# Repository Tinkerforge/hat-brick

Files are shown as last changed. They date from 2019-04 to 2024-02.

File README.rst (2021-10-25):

HAT Brick
=========

This repository contains the firmware source code and the hardware design
files. The documentation generator configs can be found at
https://github.com/Tinkerforge/generators

Repository Content
------------------

software/:
 * examples/: Examples for all supported languages
 * build/: Compiled files
 * src/: Source code of firmware
 * Makefile: Makefile to build project

hardware/:
 * Contains KiCad project files and additionally schematics as PDF

datasheets/:
 * Contains datasheets for sensors and complex ICs that are used

Hardware
--------

The hardware is designed with the open source EDA Suite KiCad
(http://www.kicad.org). Before you are able to open the files,
you have to install the Tinkerforge kicad-libraries
(https://github.com/Tinkerforge/kicad-libraries). You can either clone
them directly in hardware/ or clone them in a separate folder and
symlink them into hardware/
(ln -s kicad_path/kicad-libraries project_path/hardware). After that you
can open the .pro file in hardware/ with KiCad and from there view and
modify the schematics and the PCB layout.

Software
--------

If you want to do your own Brick/Bricklet firmware development we highly
recommend that you use our build environment setup script and read the
tutorial (https://www.tinkerforge.com/en/doc/Tutorials/Tutorial_Build_Environment/Tutorial.html).

To compile the C code we recommend you to install the newest GNU Arm Embedded
Toolchain (https://launchpad.net/gcc-arm-embedded/+download).
You also need to install bricklib2 (https://github.com/Tinkerforge/bricklib2).

You can either clone it directly in software/src/ or clone it in a
separate folder and symlink it into software/src/
(ln -s bricklib_path/bricklib2 project_path/software/src/). Finally make sure to
have CMake installed (http://www.cmake.org/cmake/resources/software.html).

After that you can build the firmware by invoking make in software/.
The firmware (.zbin) can then be found in software/build/ and uploaded
with brickv (click button "Flashing" on start screen).

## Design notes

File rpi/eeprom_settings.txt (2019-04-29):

########################################################################
# EEPROM settings text file
#
# Edit this file for your particular board and run through eepmake tool,
# then use eepflash tool to write to attached HAT ID EEPROM 
#
# Tools available:
#  eepmake   Parses EEPROM text file and creates binary .eep file
#  eepdump   Dumps a binary .eep file as human readable text (for debug)
#  eepflash  Write or read .eep binary image to/from HAT EEPROM
#
########################################################################

########################################################################
# Vendor info

# 128 bit UUID. If left at zero eepmake tool will auto-generate
# RFC 4122 compliant UUID
product_uuid b7603365-412f-47ef-a4d2-e60170d12fc1

# 16 bit product id (2126)
product_id 0x084E

# 16 bit product version
product_ver 0x001

# ASCII vendor string  (max 255 characters)
vendor "Tinkerforge GmbH"

# ASCII product string (max 255 characters)
product "HAT Brick"

########################################################################
# GPIO bank settings, set to nonzero to change from the default.
# NOTE these setting can only be set per BANK, uncommenting any of
# these will force the bank to use the custom setting.

# drive strength, 0=default, 1-8=2,4,6,8,10,12,14,16mA, 9-15=reserved
gpio_drive 0

# 0=default, 1=slew rate limiting, 2=no slew limiting, 3=reserved
gpio_slew 0

# 0=default, 1=hysteresis disabled, 2=hysteresis enabled, 3=reserved
gpio_hysteresis 0

# If board back-powers Pi via 5V GPIO header pins:
# 0 = board does not back-power
# 1 = board back-powers and can supply the Pi with a minimum of 1.3A
# 2 = board back-powers and can supply the Pi with a minimum of 2A
# 3 = reserved
# If back_power=2 then USB high current mode will be automatically 
# enabled on the Pi
back_power 1

########################################################################
# GPIO pins, uncomment for GPIOs used on board
# Options for FUNCTION: INPUT, OUTPUT, ALT0-ALT5
# Options for PULL: DEFAULT, UP, DOWN, NONE
# NB GPIO0 and GPIO1 are reserved for ID EEPROM so cannot be set

#         GPIO  FUNCTION  PULL
#         ----  --------  ----
#setgpio  2     INPUT     DEFAULT
#setgpio  3     INPUT     DEFAULT
#setgpio  4     INPUT     DEFAULT
setgpio  5     OUTPUT     UP           # Chip Select
setgpio  6     OUTPUT     UP           # Chip Select
setgpio  7     OUTPUT     UP           # Chip Select
#setgpio  8     INPUT     DEFAULT
#setgpio  9     INPUT     DEFAULT
#setgpio  10    INPUT     DEFAULT
#setgpio  11    INPUT     DEFAULT
#setgpio  12    INPUT     DEFAULT
#setgpio  13    INPUT     DEFAULT
#setgpio  14    INPUT     DEFAULT
#setgpio  15    INPUT     DEFAULT
#setgpio  16    INPUT     DEFAULT
#setgpio  17    INPUT     DEFAULT
#setgpio  18    INPUT     DEFAULT
#setgpio  19    INPUT     DEFAULT
#setgpio  20    INPUT     DEFAULT
#setgpio  21    INPUT     DEFAULT
setgpio  22    OUTPUT     UP           # Chip Select
setgpio  23    OUTPUT     UP           # Chip Select
setgpio  24    OUTPUT     UP           # Chip Select
setgpio  25    OUTPUT     UP           # Chip Select
setgpio  26    OUTPUT     UP           # Chip Select
setgpio  27    OUTPUT     UP           # Chip Select

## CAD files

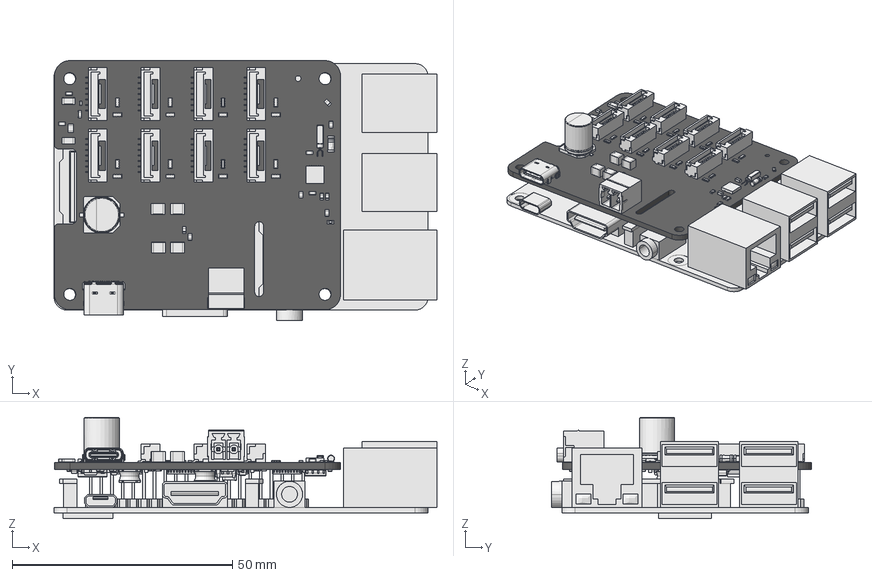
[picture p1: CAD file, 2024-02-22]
hardware/hat.FCStd
87.0 x 59.0 x 23.0 mm
Pcb_34c2
C102_C_0603_00005b3742ad
C103_C_0603_00005b3742b7
C107_C_1206_00005b3742df
C110_C_1206_00005b3742fd
C111_C_0603_00005b374307
c_el_F_D80_L100
CP301_Cut_00005b37446e
CP302_Cut_00005b37447e
CP303_Cut_00005b37448e
CP304_Cut_00005b37449e
CP305_Cut_00005b3744ae
CP306_Cut_00005b3744be
CP307_Cut_00005b3744ce
CP308_Cut_00005b3744de
L102_R_0805_00005b3745df
P201_2er_Phoenix_Buchse_Grün_00005b374602
P301_BrickletConn_7pin_180_00005b374615
P302_BrickletConn_7pin_180_00005b374628
P303_BrickletConn_7pin_180_00005b37463b
P304_BrickletConn_7pin_180_00005b37464e
P305_BrickletConn_7pin_180_00005b374661
P306_BrickletConn_7pin_180_00005b374674
P307_BrickletConn_7pin_180_00005b374687
P308_BrickletConn_7pin_180_00005b37469a
R101_R_0603_00005b3746d0
R102_R_0603_00005b3746da
RP301_Cut_00005b374814
RP302_Cut_00005b374824
RP303_Cut_00005b374834
RP304_Cut_00005b374844
RP305_Cut_00005b374854
RP306_Cut_00005b374864
RP307_Cut_00005b374874
RP308_Cut_00005b374884
R103_R_0603_00005b45ae8f
X101_AB26TRQ_00005b6d9510
C203_C_1210_00005c675905
R104_R_0603_00005c6b70e3
C114_C_0603_00005c6c6956
C116_C_0402_00005c6d4534
R105_R_0603_00005c6f29cb
U101_QFN-24_4x4mm_Pitch0.5mm_00005c6f29dc
USB4105
USB4106
C105_C_0603_00005e7b179c
C6_C_1210_f720f5794206
R2_R_0603_bf9c9aada493
R3_R_0603_2c3d8f72ff8d
C2_C_1210_26456e1a1afe
R1_R_0603_8b455849e99a
C1_C_1210_014f6602df92
C104_C_0603_00005b3742c1
C108_C_1206_00005b3742e9
C109_C_0603_00005b3742f3
C112_C_1206_00005b374311
C301_C_0603_00005b374440
C302_C_0603_00005b37444a
C303_C_0603_00005b374454
C304_C_0603_00005b37445e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

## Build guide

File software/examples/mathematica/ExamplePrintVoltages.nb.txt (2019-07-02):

Needs["NETLink`"]
LoadNETAssembly["Tinkerforge",NotebookDirectory[]<>"../../.."]

host="localhost"
port=4223
uid="XXYYZZ"(*Change XXYYZZ to the UID of your HAT Brick*)

(*Create IPConnection and device object*)
ipcon=NETNew["Tinkerforge.IPConnection"]
hat=NETNew["Tinkerforge.BrickHAT",uid,ipcon]
ipcon@Connect[host,port]

(*Get current get voltages*)
voltageUSB=0;voltageDC=0
hat@GetVoltages[voltageUSB,voltageDC]

Print["Voltage USB: "<>ToString[N[Quantity[voltageUSB,"V/1000"]]]]
Print["Voltage DC: "<>ToString[N[Quantity[voltageDC,"V/1000"]]]]

(*Clean up*)
ipcon@Disconnect[]
ReleaseNETObject[hat]
ReleaseNETObject[ipcon]

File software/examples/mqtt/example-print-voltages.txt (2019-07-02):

# Change XXYYZZ to the UID of your HAT Brick

setup:
	# Get current get voltages
	subscribe to tinkerforge/response/hat_brick/XXYYZZ/get_voltages
	publish '' to tinkerforge/request/hat_brick/XXYYZZ/get_voltages

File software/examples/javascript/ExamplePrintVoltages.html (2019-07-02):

# HAT Brick Print Voltages Example

: ,

Press "Start Example" to begin ...

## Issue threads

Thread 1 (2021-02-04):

Perform clean shutdown of Pi

bablokb, 2021-02-04:
A suggestion for the  next hardware revision: if you connect two additional pins from the mcu to the Pi you could cleanly shutdown the Pi before turning power off. The delay before going to sleep would also not be necessary anymore.

The trick is to add two overlays to `/boot/config.txt`:

    dtoverlay=gpio-shutdown,gpio_pin=x
    dtoverlay=gpio-poweroff,gpiopin=y

The first overlay will initiate shutdown, when x becomes low. When the shutdown is finished, the second overlay will pull y high and you can turn off power. Depending on the pins you choose for gpio-poweroff, you might have to implement some grace period during booting, because the pin could be high for a very short time during boot.

I checked your kicad-files and it seems that you still have two pins left.

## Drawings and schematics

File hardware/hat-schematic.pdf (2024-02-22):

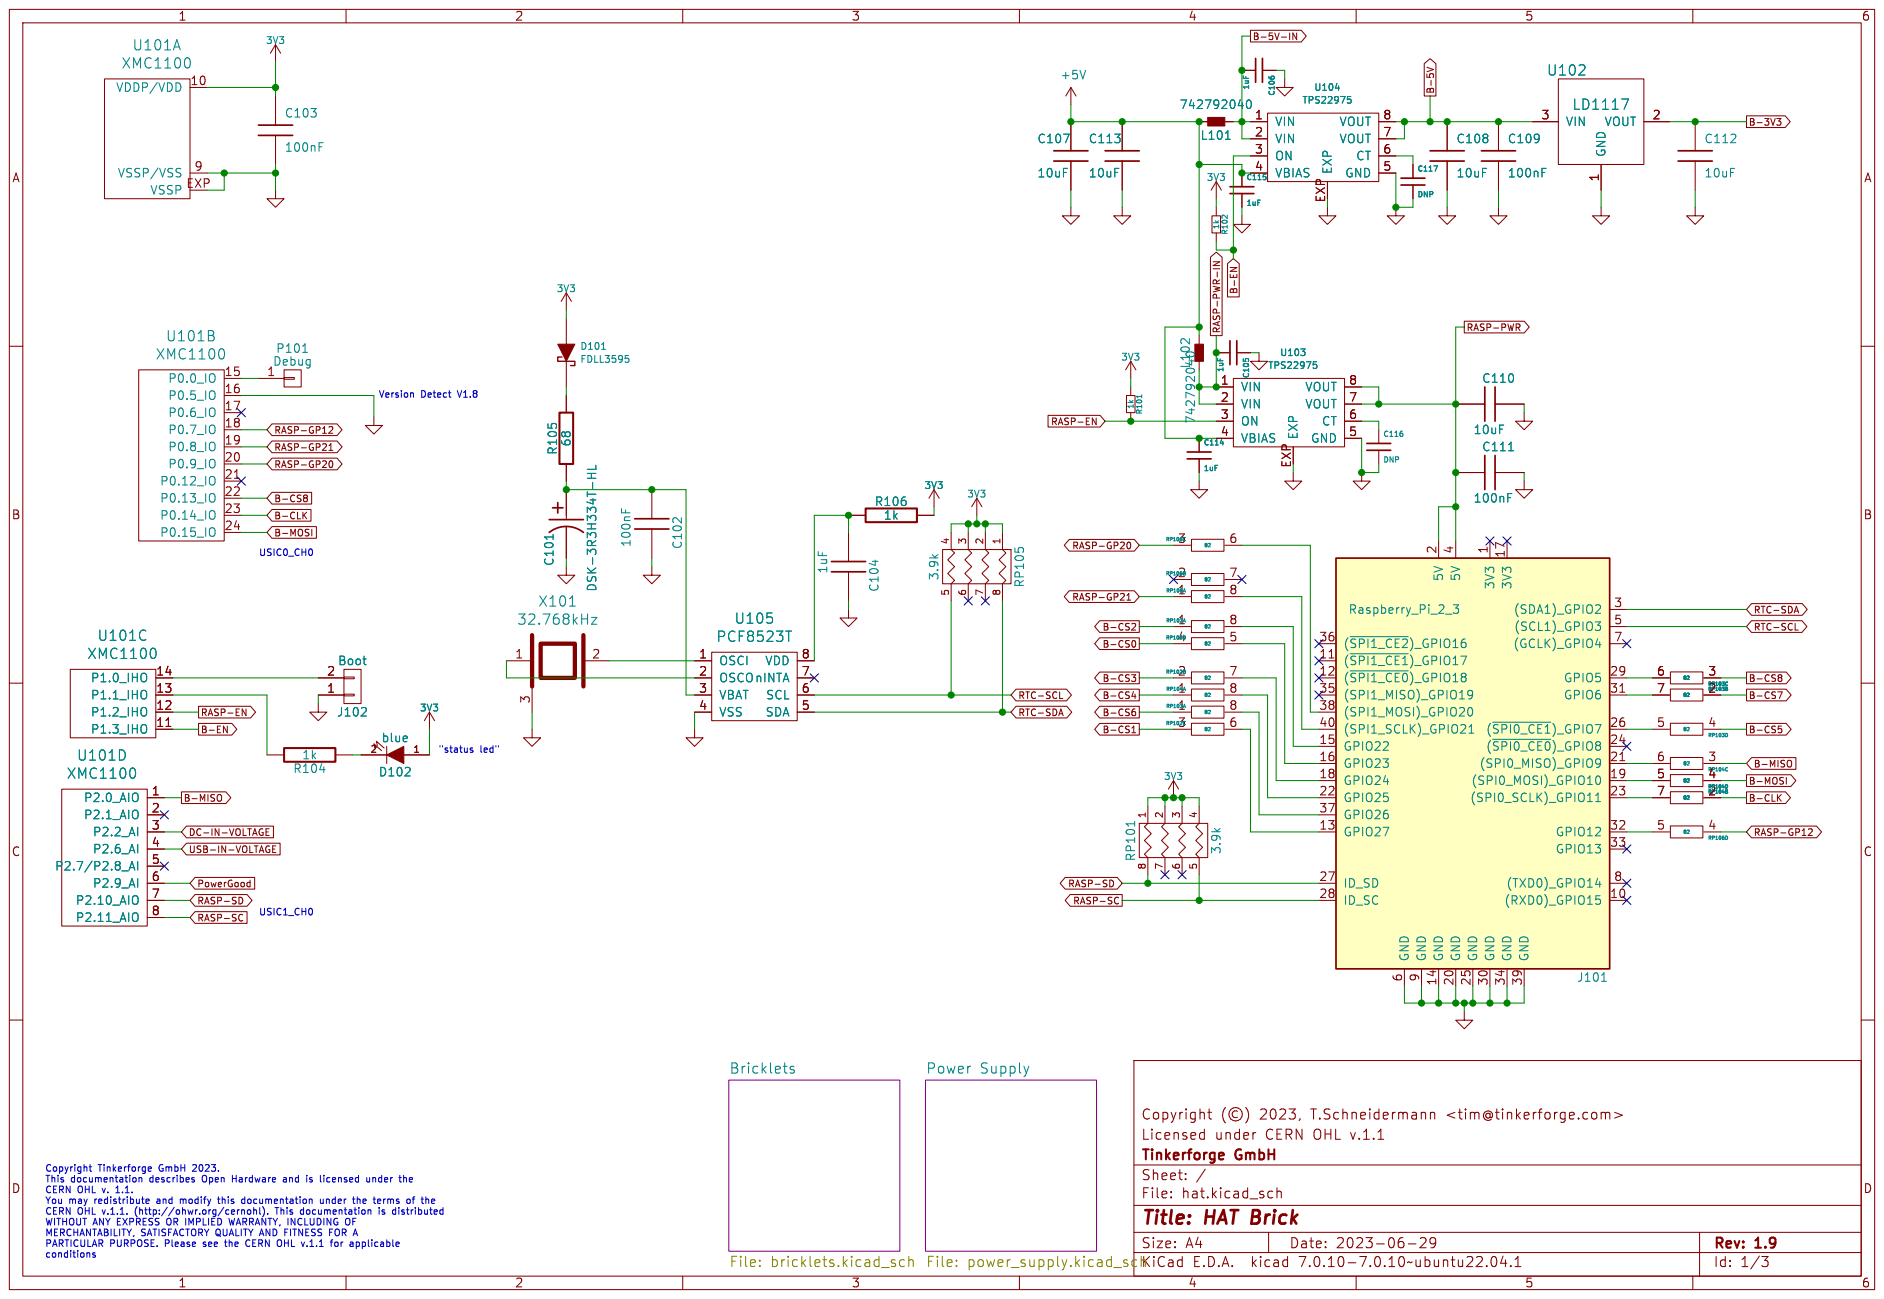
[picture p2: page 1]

PowerGood USB-IN-VOLTAGE DC-IN-VOLTAGE

File: hat.kicad_sch Sheet: / Tinkerforge GmbH

Id: 1/3 Title: HAT Brick

PARTICULAR PURPOSE. Please see the CERN OHL v.1.1 for applicable
conditions

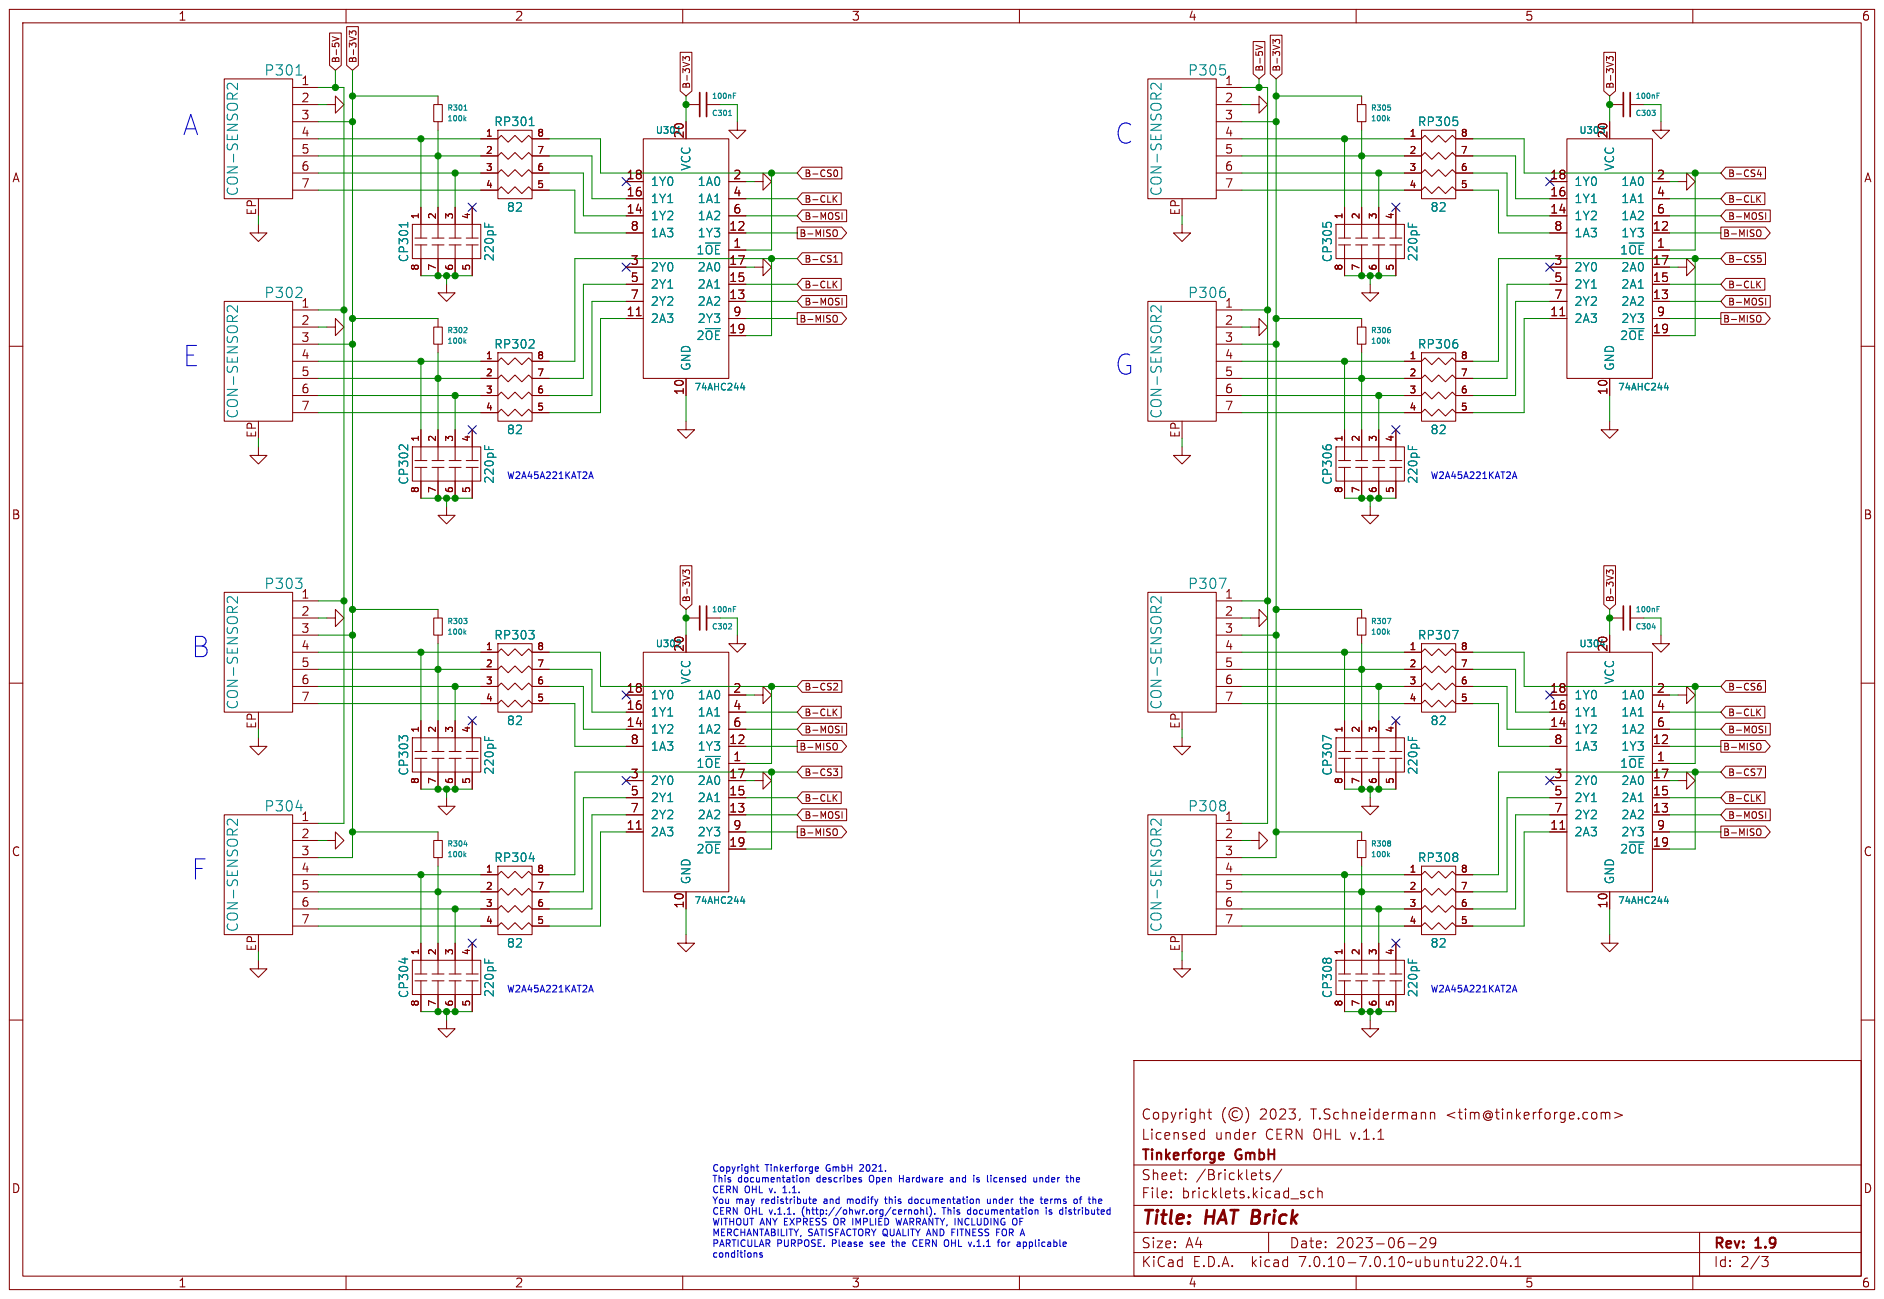
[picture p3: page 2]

File: bricklets.kicad_sch Sheet: /Bricklets/ Tinkerforge GmbH

Id: 2/3 Title: HAT Brick

PARTICULAR PURPOSE. Please see the CERN OHL v.1.1 for applicable

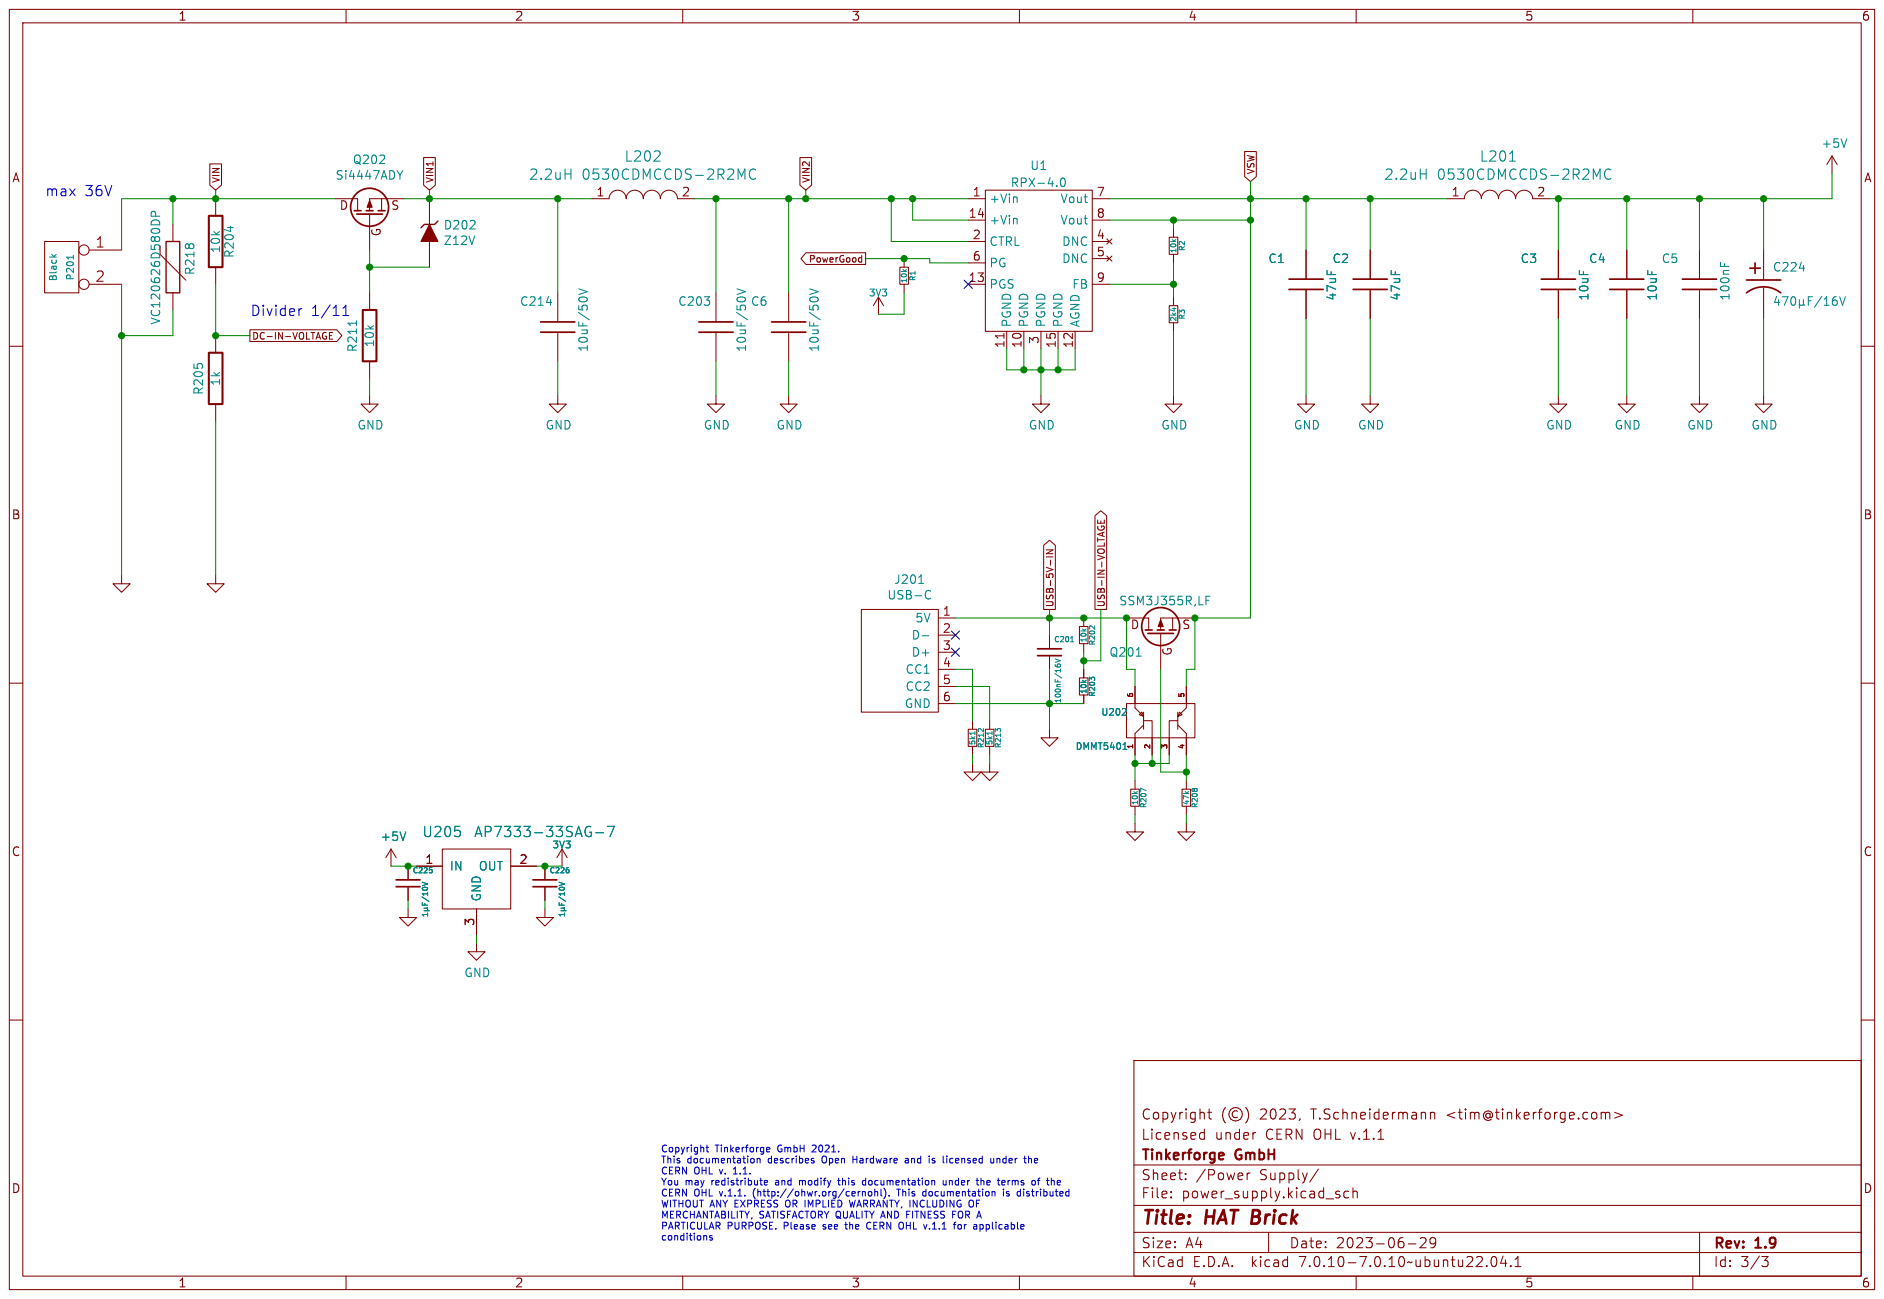
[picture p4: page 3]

3 DNC 4 DNC 5 PG 6 Vout 7 Vout 8 FB 9 U1 RPX-4.0

5 U202 DMMT5401 R203 10k +Vin 1 PGND 10 PGND 11 AGND 12 PGS 13 +Vin 14 PGND 15 CTRL 2 PGND

Tinkerforge GmbH
Id: 3/3 Title: HAT Brick

PARTICULAR PURPOSE. Please see the CERN OHL v.1.1 for applicable
conditions

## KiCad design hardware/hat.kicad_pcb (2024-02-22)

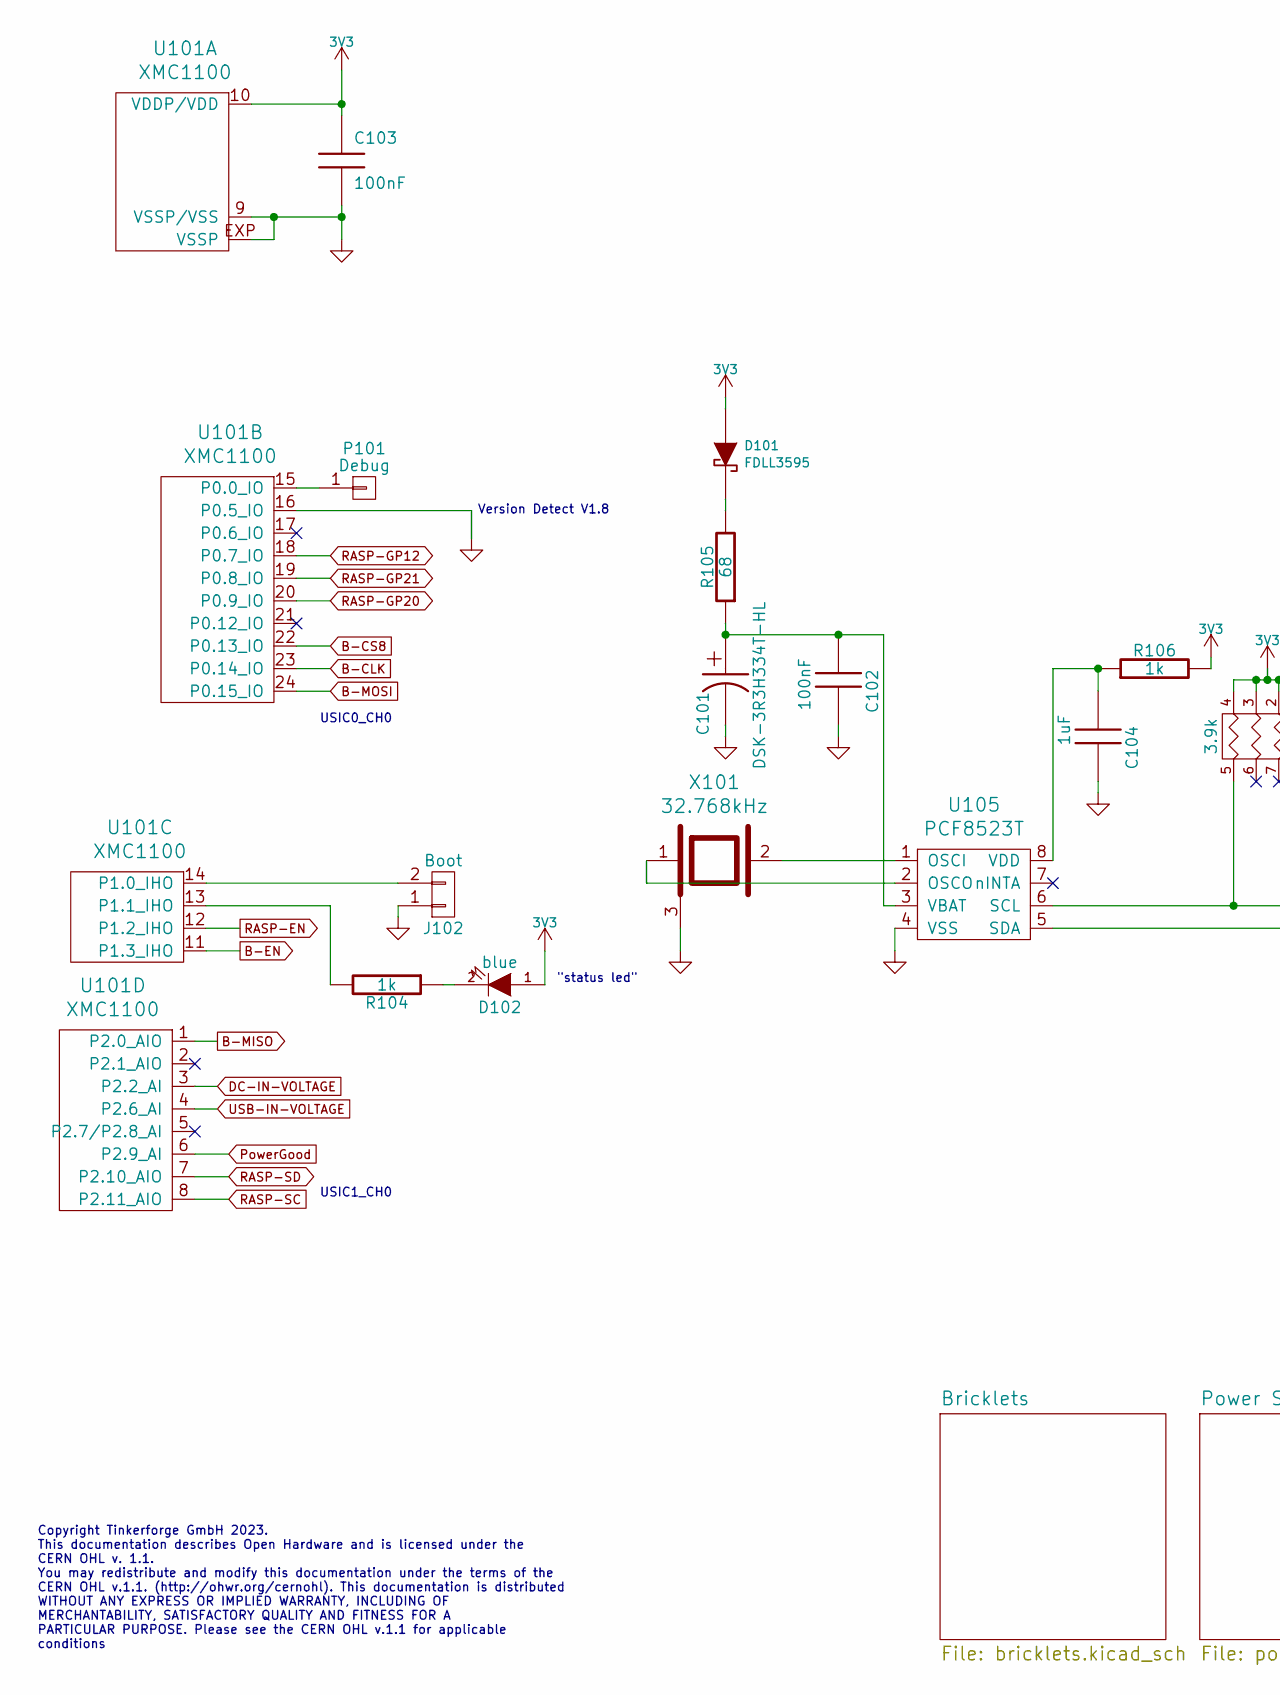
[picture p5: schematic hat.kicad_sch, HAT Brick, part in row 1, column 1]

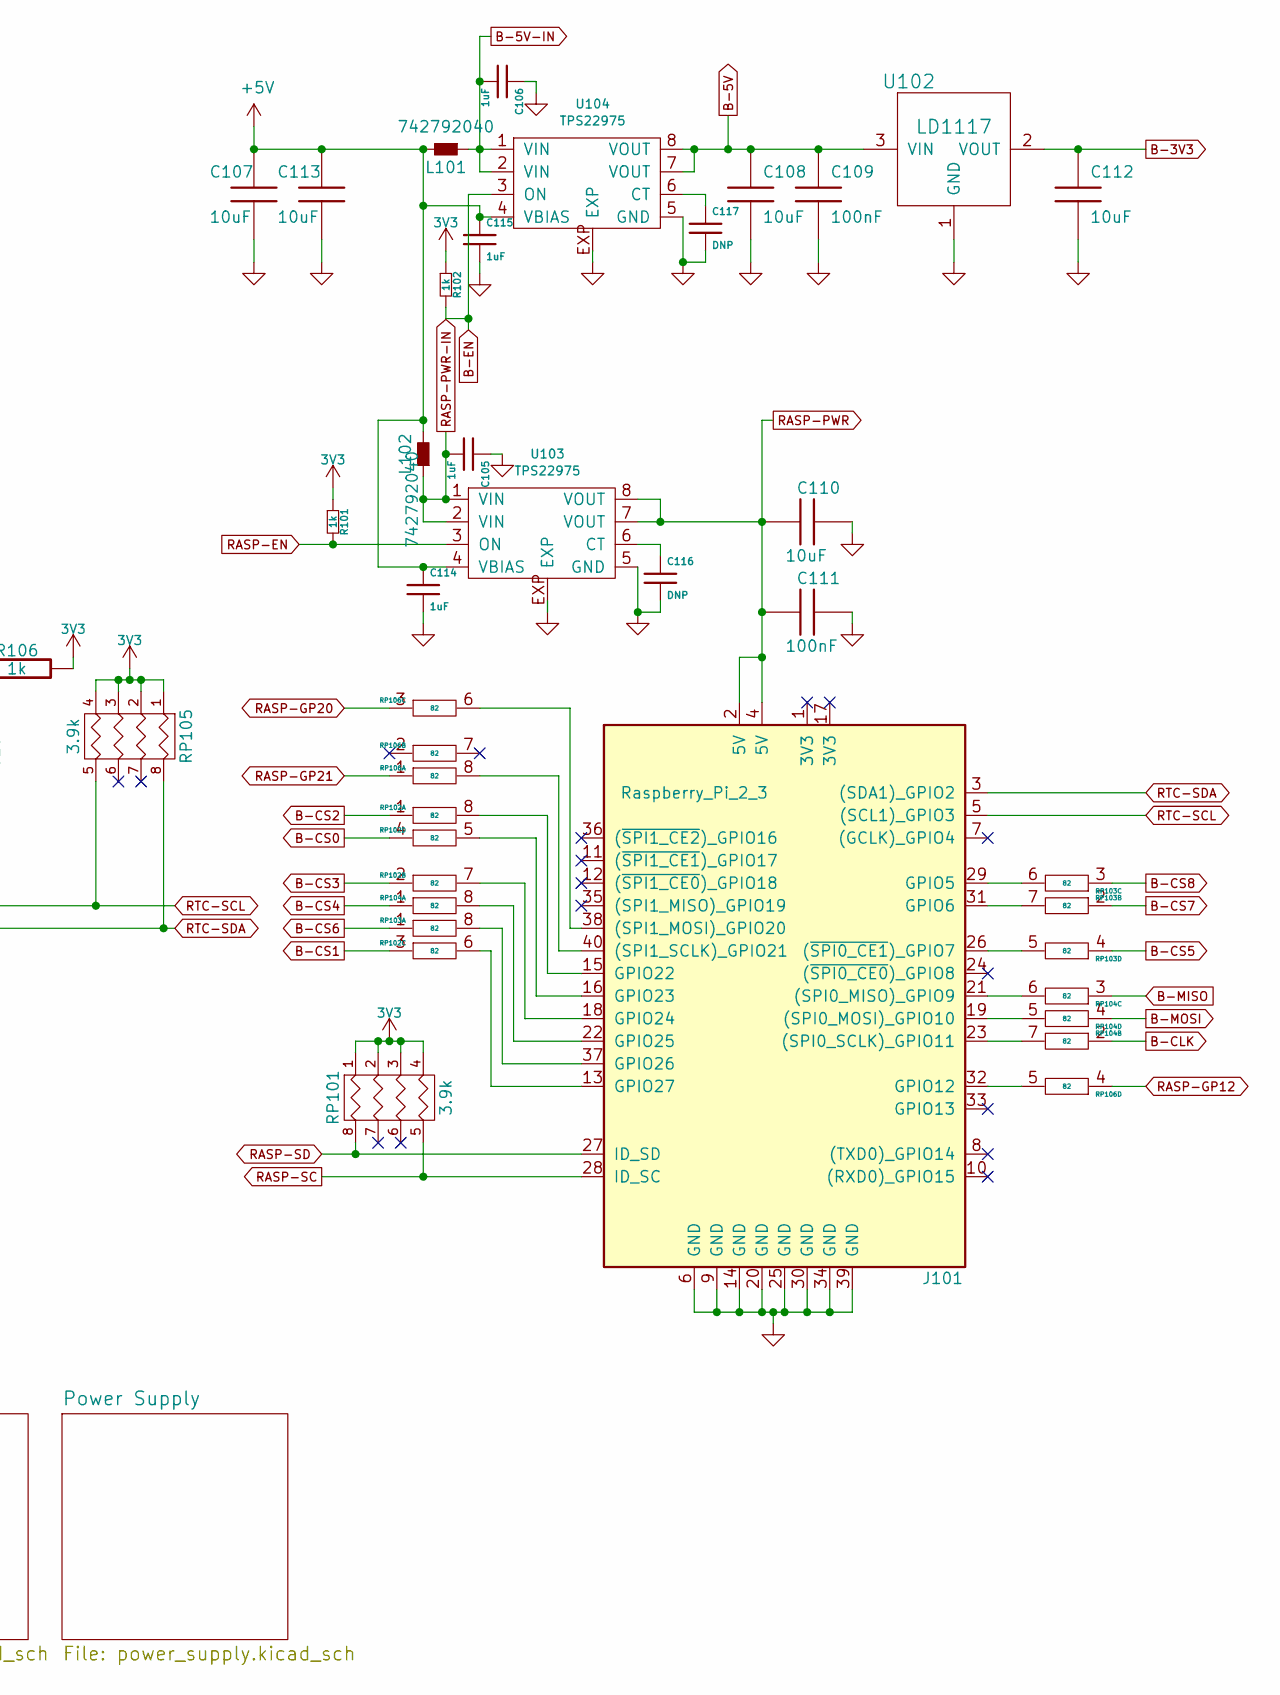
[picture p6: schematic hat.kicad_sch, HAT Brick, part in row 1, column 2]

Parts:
C101: DSK-3R3H334T-HL; DSK
C102, C103, C109, C111: 100nF; C0603F
C104, C105, C106, C114, C115: 1uF; C0603F
C107, C108, C110, C112, C113: 10uF; C1206
C116, C117: DNP; C0402F
D101: FDLL3595; MiniMelf
D102: blue; D0603F
J101: Raspberry_Pi_2_3; raspberrypi_hat2
J102: Boot; SolderJumper
L101, L102: 742792040; R0805
P101: Debug; DEBUG_PAD
R101, R102, R104, R106: 1k; R0603F
R105: 68; R0603F
RP101, RP105: 3.9k; 4X0402
RP102, RP103, RP104, RP106: 82; 4X0402
U101: XMC1100; QFN24-4x4mm-0.5mm
U102: LD1117; SOT-223
U103, U104: TPS22975; WSON8-2x2
U105: PCF8523T; SO-8
X101: 32.768kHz; AB26TRQ

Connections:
3V3: C103.1, D101.1 (A), D102.1 (A), R101.1, R102.1, R106.2, RP101.1, RP101.2, RP101.3, RP101.4, RP105.1, RP105.2, RP105.3, RP105.4, U101.10 (VDDP/VDD); also elsewhere on the board
+5V: C107.1, C113.1, C114.1, C115.1, L101.2, L102.2, U103.4 (VBIAS), U104.4 (VBIAS); also elsewhere on the board
B-3V3: C112.1, U102.2 (VOUT); also elsewhere on the board
B-5V: C108.1, C109.1, U102.3 (VIN), U104.7 (VOUT), U104.8 (VOUT); also elsewhere on the board
B-5V-IN: C106.2, L101.1, U104.1 (VIN), U104.2 (VIN)
B-CLK: RP104.2, U101.23 (P0.14_IO); also elsewhere on the board
B-CS0: RP102.4; also elsewhere on the board
B-CS1: RP102.3; also elsewhere on the board
B-CS2: RP102.1; also elsewhere on the board
B-CS3: RP102.2; also elsewhere on the board
B-CS4: RP104.1; also elsewhere on the board
B-CS5: RP103.4; also elsewhere on the board
B-CS6: RP103.1; also elsewhere on the board
B-CS7: RP103.2; also elsewhere on the board
B-CS8: RP103.3, U101.22 (P0.13_IO)
B-EN: R102.2, U101.11 (P1.3_IHO), U104.3 (ON)
B-MISO: RP104.3, U101.1 (P2.0_AIO); also elsewhere on the board
B-MOSI: RP104.4, U101.24 (P0.15_IO); also elsewhere on the board
DC-IN-VOLTAGE: U101.3 (P2.2_AI); also elsewhere on the board
GND: C101.2, C102.1, C103.2, C104.1, C105.1, C106.1, C107.2, C108.2, C109.2, C110.1, C111.1, C112.2, C113.2, C114.2, C115.2, C116.2, C117.2, J101.6 (GND), J101.9 (GND), J101.14 (GND), J101.20 (GND), J101.25 (GND), J101.30 (GND), J101.34 (GND), J101.39 (GND), J102.1, U101.9 (VSSP/VSS), U101.16 (P0.5_IO), U101.EXP (VSSP), U102.1 (GND), U103.5 (GND), U103.EXP, U104.5 (GND), U104.EXP, U105.4 (VSS), X101.3; also elsewhere on the board
unnamed: C101.1, C102.2, R105.1, U105.3 (VBAT)
unnamed: C104.2, R106.1, U105.8 (VDD)
unnamed: C116.1, U103.6 (CT)
unnamed: C117.1, U104.6 (CT)
unnamed: D101.2 (K), R105.2
unnamed: D102.2 (K), R104.1
unnamed: J101.13 (GPIO27), RP102.6
unnamed: J101.15 (GPIO22), RP102.8
unnamed: J101.16 (GPIO23), RP102.5
unnamed: J101.18 (GPIO24), RP102.7
unnamed: J101.19 ((SPI0_MOSI)_GPIO10), RP104.5
unnamed: J101.21 ((SPI0_MISO)_GPIO9), RP104.6
unnamed: J101.22 (GPIO25), RP104.8
unnamed: J101.23 ((SPI0_SCLK)_GPIO11), RP104.7
unnamed: J101.26 ((~SPI0_CE1)_GPIO7), RP103.5
unnamed: J101.29 (GPIO5), RP103.6
unnamed: J101.31 (GPIO6), RP103.7
unnamed 62: J101.32 (GPIO12), RP106.5; also elsewhere on the board
unnamed: J101.37 (GPIO26), RP103.8
unnamed: J102.2, U101.14 (P1.0_IHO)
unnamed: P101.1, U101.15 (P0.0_IO)
unnamed: R104.2, U101.13 (P1.1_IHO)
unnamed: RP106.1, U101.19 (P0.8_IO)
unnamed: RP106.3, U101.20 (P0.9_IO)
unnamed: J101.38 ((SPI1_MOSI)_GPIO20), RP106.6
unnamed: J101.40 ((SPI1_SCLK)_GPIO21), RP106.8
unnamed: U105.1 (OSCI), X101.2
unnamed: U105.2 (OSCO), X101.1
PowerGood: U101.6 (P2.9_AI); also elsewhere on the board
RASP-EN: R101.2, U101.12 (P1.2_IHO), U103.3 (ON)
RASP-GP: RP106.4, U101.18 (P0.7_IO); also elsewhere on the board
RASP-PWR: C110.2, C111.2, J101.2 (5V), J101.4 (5V), U103.7 (VOUT), U103.8 (VOUT)
RASP-PWR-IN: C105.2, L102.1, U103.1 (VIN), U103.2 (VIN)
RASP-SC: J101.28 (ID_SC), RP101.5 (R4), U101.8 (P2.11_AIO)
RASP-SD: J101.27 (ID_SD), RP101.8 (R1), U101.7 (P2.10_AIO)
RTC-SCL: J101.5 ((SCL1)_GPIO3), RP105.5 (R4), U105.6 (SCL)
RTC-SDA: J101.3 ((SDA1)_GPIO2), RP105.8 (R1), U105.5 (SDA)
USB-IN-VOLTAGE: U101.4 (P2.6_AI); also elsewhere on the board

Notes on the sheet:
"status led"
USIC1_CH0
Version Detect V1.8
Copyright Tinkerforge GmbH 2023. This documentation describes Open Hardware and is licensed under the CERN OHL v. 1.1. You may redistribute and modify this documentation under the terms of the CERN OHL v.1.1. (http://ohwr.org/cernohl). This documentation is distributed WITHOUT ANY EXPRESS OR IMPLIE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
USIC0_CH0

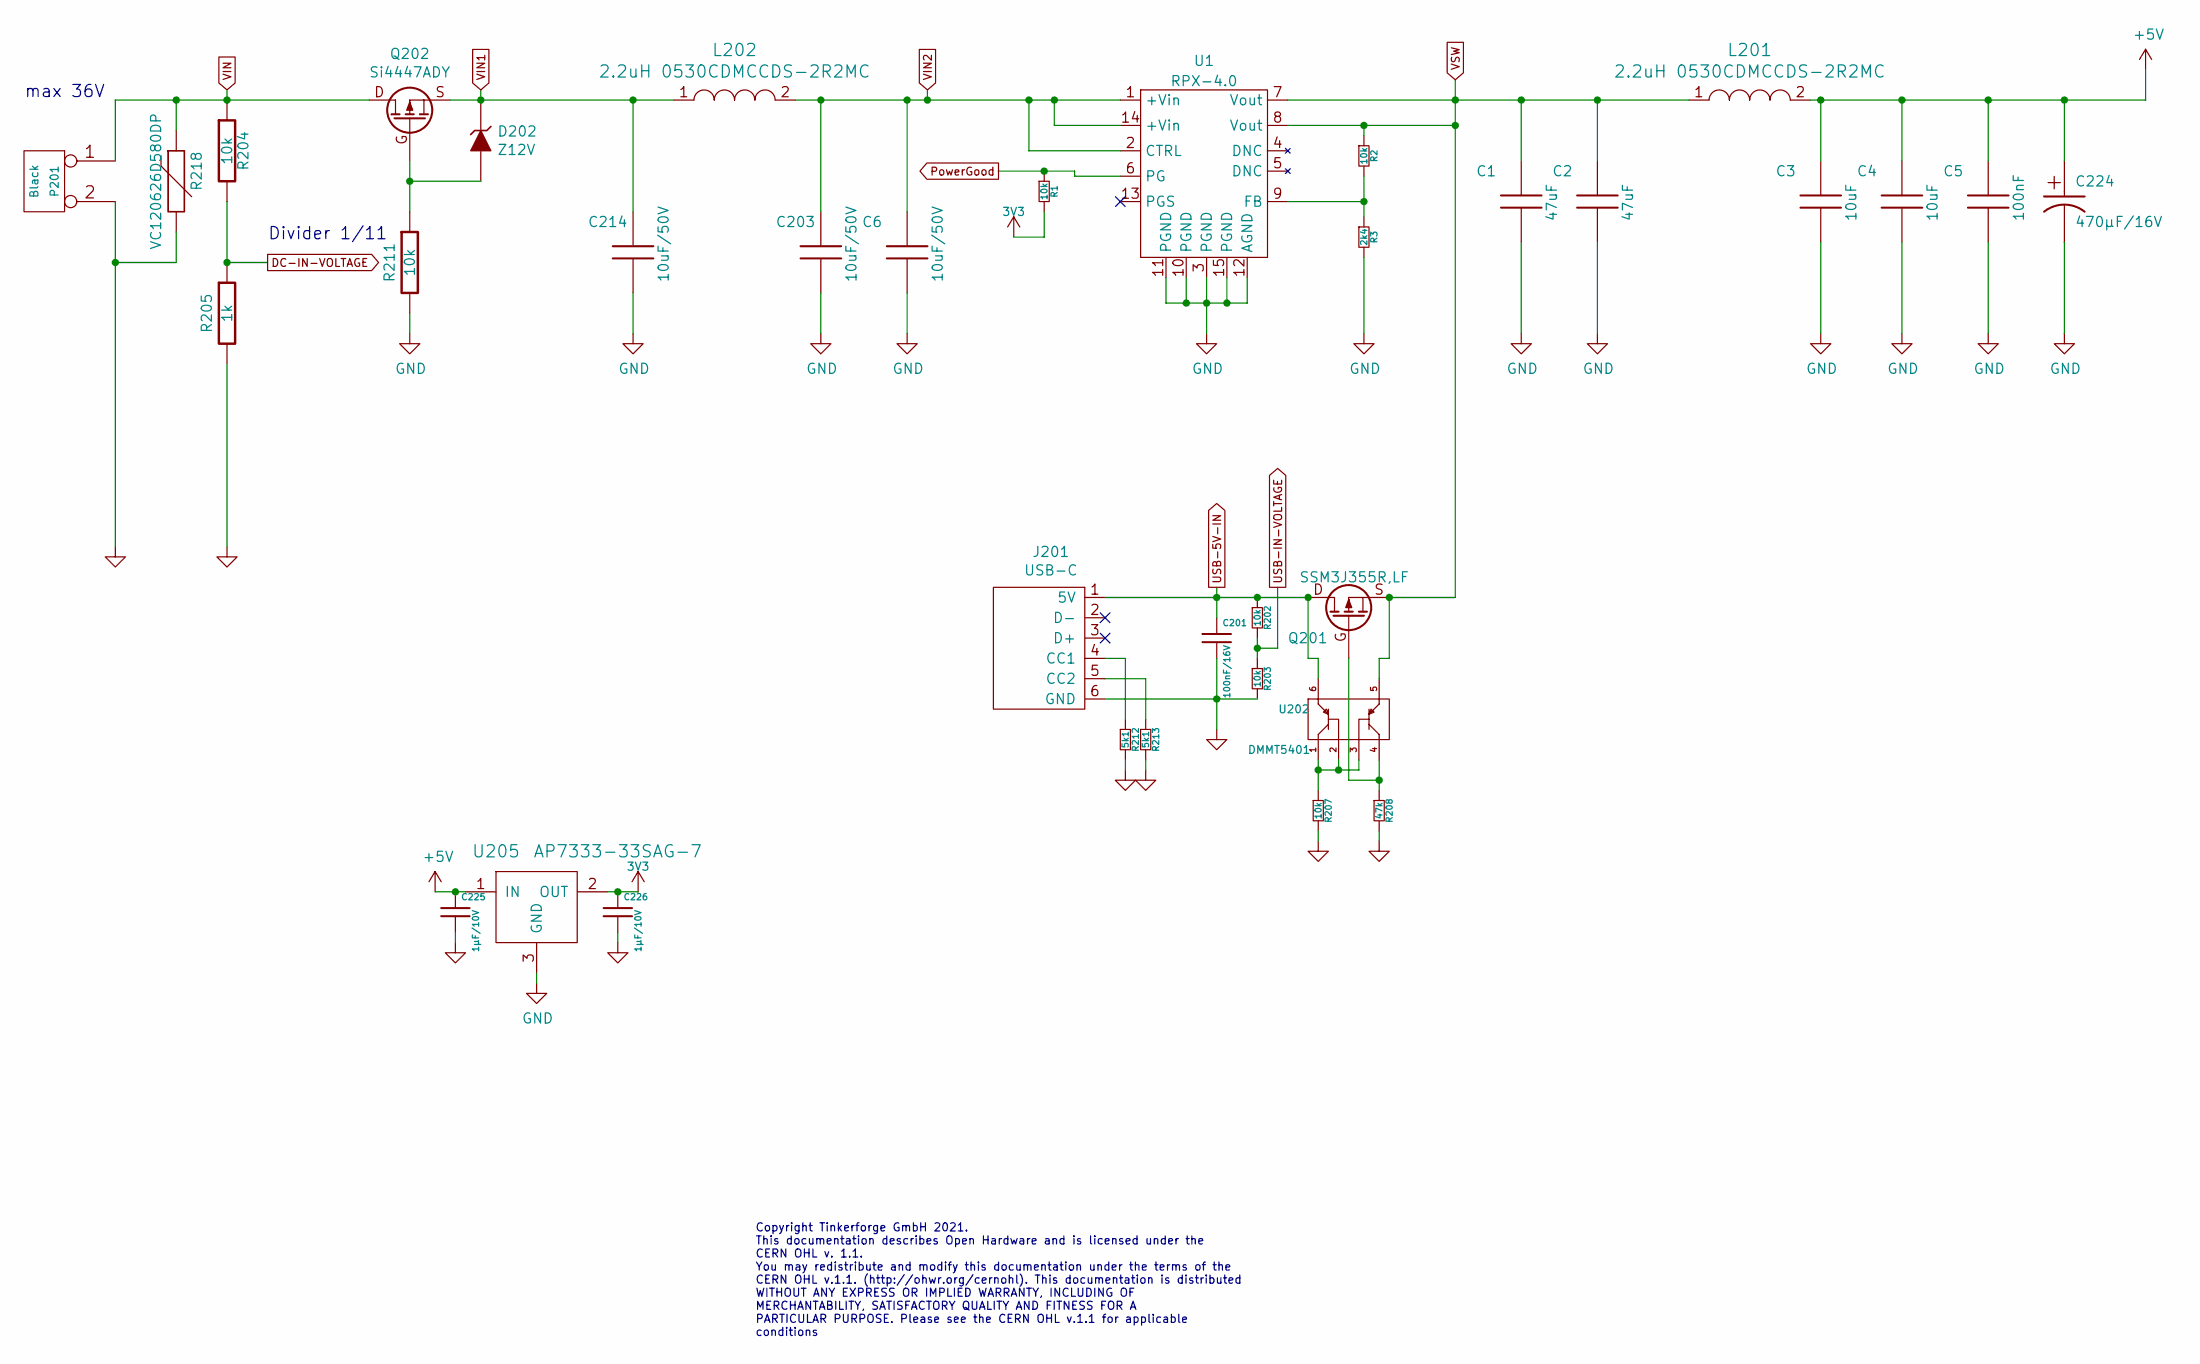
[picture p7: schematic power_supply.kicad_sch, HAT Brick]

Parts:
C1, C2: 47uF; C1210
C3, C4: 10uF; C0805E
C5: 100nF; C0603F
C6, C203, C214: 10uF/50V; C1210
C201: 100nF/16V; C0603F
C224: 470µF/16V; ELKO_83
C225, C226: 1µF/10V; C0603F
D202: Z12V; SOD-123
J201: USB-C
L201, L202: 2.2uH 0530CDMCCDS-2R2MC; NRS5030
P201: Black; OQ_2P
Q201: SSM3J355R,LF; SOT23GDS
Q202: Si4447ADY; SOIC-8-MOSFET
R1, R2, R202, R203, R204, R207, R211: 10k; R0603F
R3: 2k4; R0603F
R205: 1k; R0603F
R208: 47k; R0603F
R212, R213: 5k1; R0603F
R218: VC120626D580DP; R1206
U1: RPX-4.0
U202: DMMT5401; SOT26
U205: AP7333-33SAG-7; SOT23-3

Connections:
3V3: C226.1, R1.2, U205.2 (OUT); also elsewhere on the board
+5V: C3.1, C4.1, C5.1, C224.1, C225.1, L201.2, U205.1 (IN); also elsewhere on the board
DC-IN-VOLTAGE: R204.2, R205.1; also elsewhere on the board
GND: C1.2, C2.2, C3.2, C4.2, C5.2, C6.2, C201.2, C203.2, C214.2, C224.2, C225.2, C226.2, J201.6 (GND), P201.2 (PM), R3.2, R203.2, R205.2, R207.2, R208.2, R211.2, R212.2, R213.2, R218.2, U1.3 (PGND), U1.10 (PGND), U1.11 (PGND), U1.12 (AGND), U1.15 (PGND), U205.3 (GND); also elsewhere on the board
unnamed: D202.1 (A), Q202.G, R211.1
unnamed: J201.4 (CC1), R212.1
unnamed: J201.5 (CC2), R213.1
unnamed: Q201.G, R208.1, U202.4
unnamed: R2.2, R3.1, U1.9 (FB)
unnamed: R207.1, U202.1, U202.2, U202.3
PowerGood: R1.1, U1.6 (PG); also elsewhere on the board
USB-5V-IN: C201.1, J201.1 (5V), Q201.D, R202.1, U202.6
USB-IN-VOLTAGE: R202.2, R203.1; also elsewhere on the board
VIN: P201.1, Q202.D, R204.1, R218.1
VIN1: C214.1, D202.2 (K), L202.1, Q202.S
VIN2: C6.1, C203.1, L202.2, U1.1 (+Vin), U1.2 (CTRL), U1.14 (+Vin)
VSW: C1.1, C2.1, L201.1, Q201.S, R2.1, U1.7 (Vout), U1.8 (Vout), U202.5

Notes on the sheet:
Divider 1/11
Copyright Tinkerforge GmbH 2021. This documentation describes Open Hardware and is licensed under the CERN OHL v. 1.1. You may redistribute and modify this documentation under the terms of the CERN OHL v.1.1. (http://ohwr.org/cernohl). This documentation is distributed WITHOUT ANY EXPRESS OR IMPLIE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
max 36V

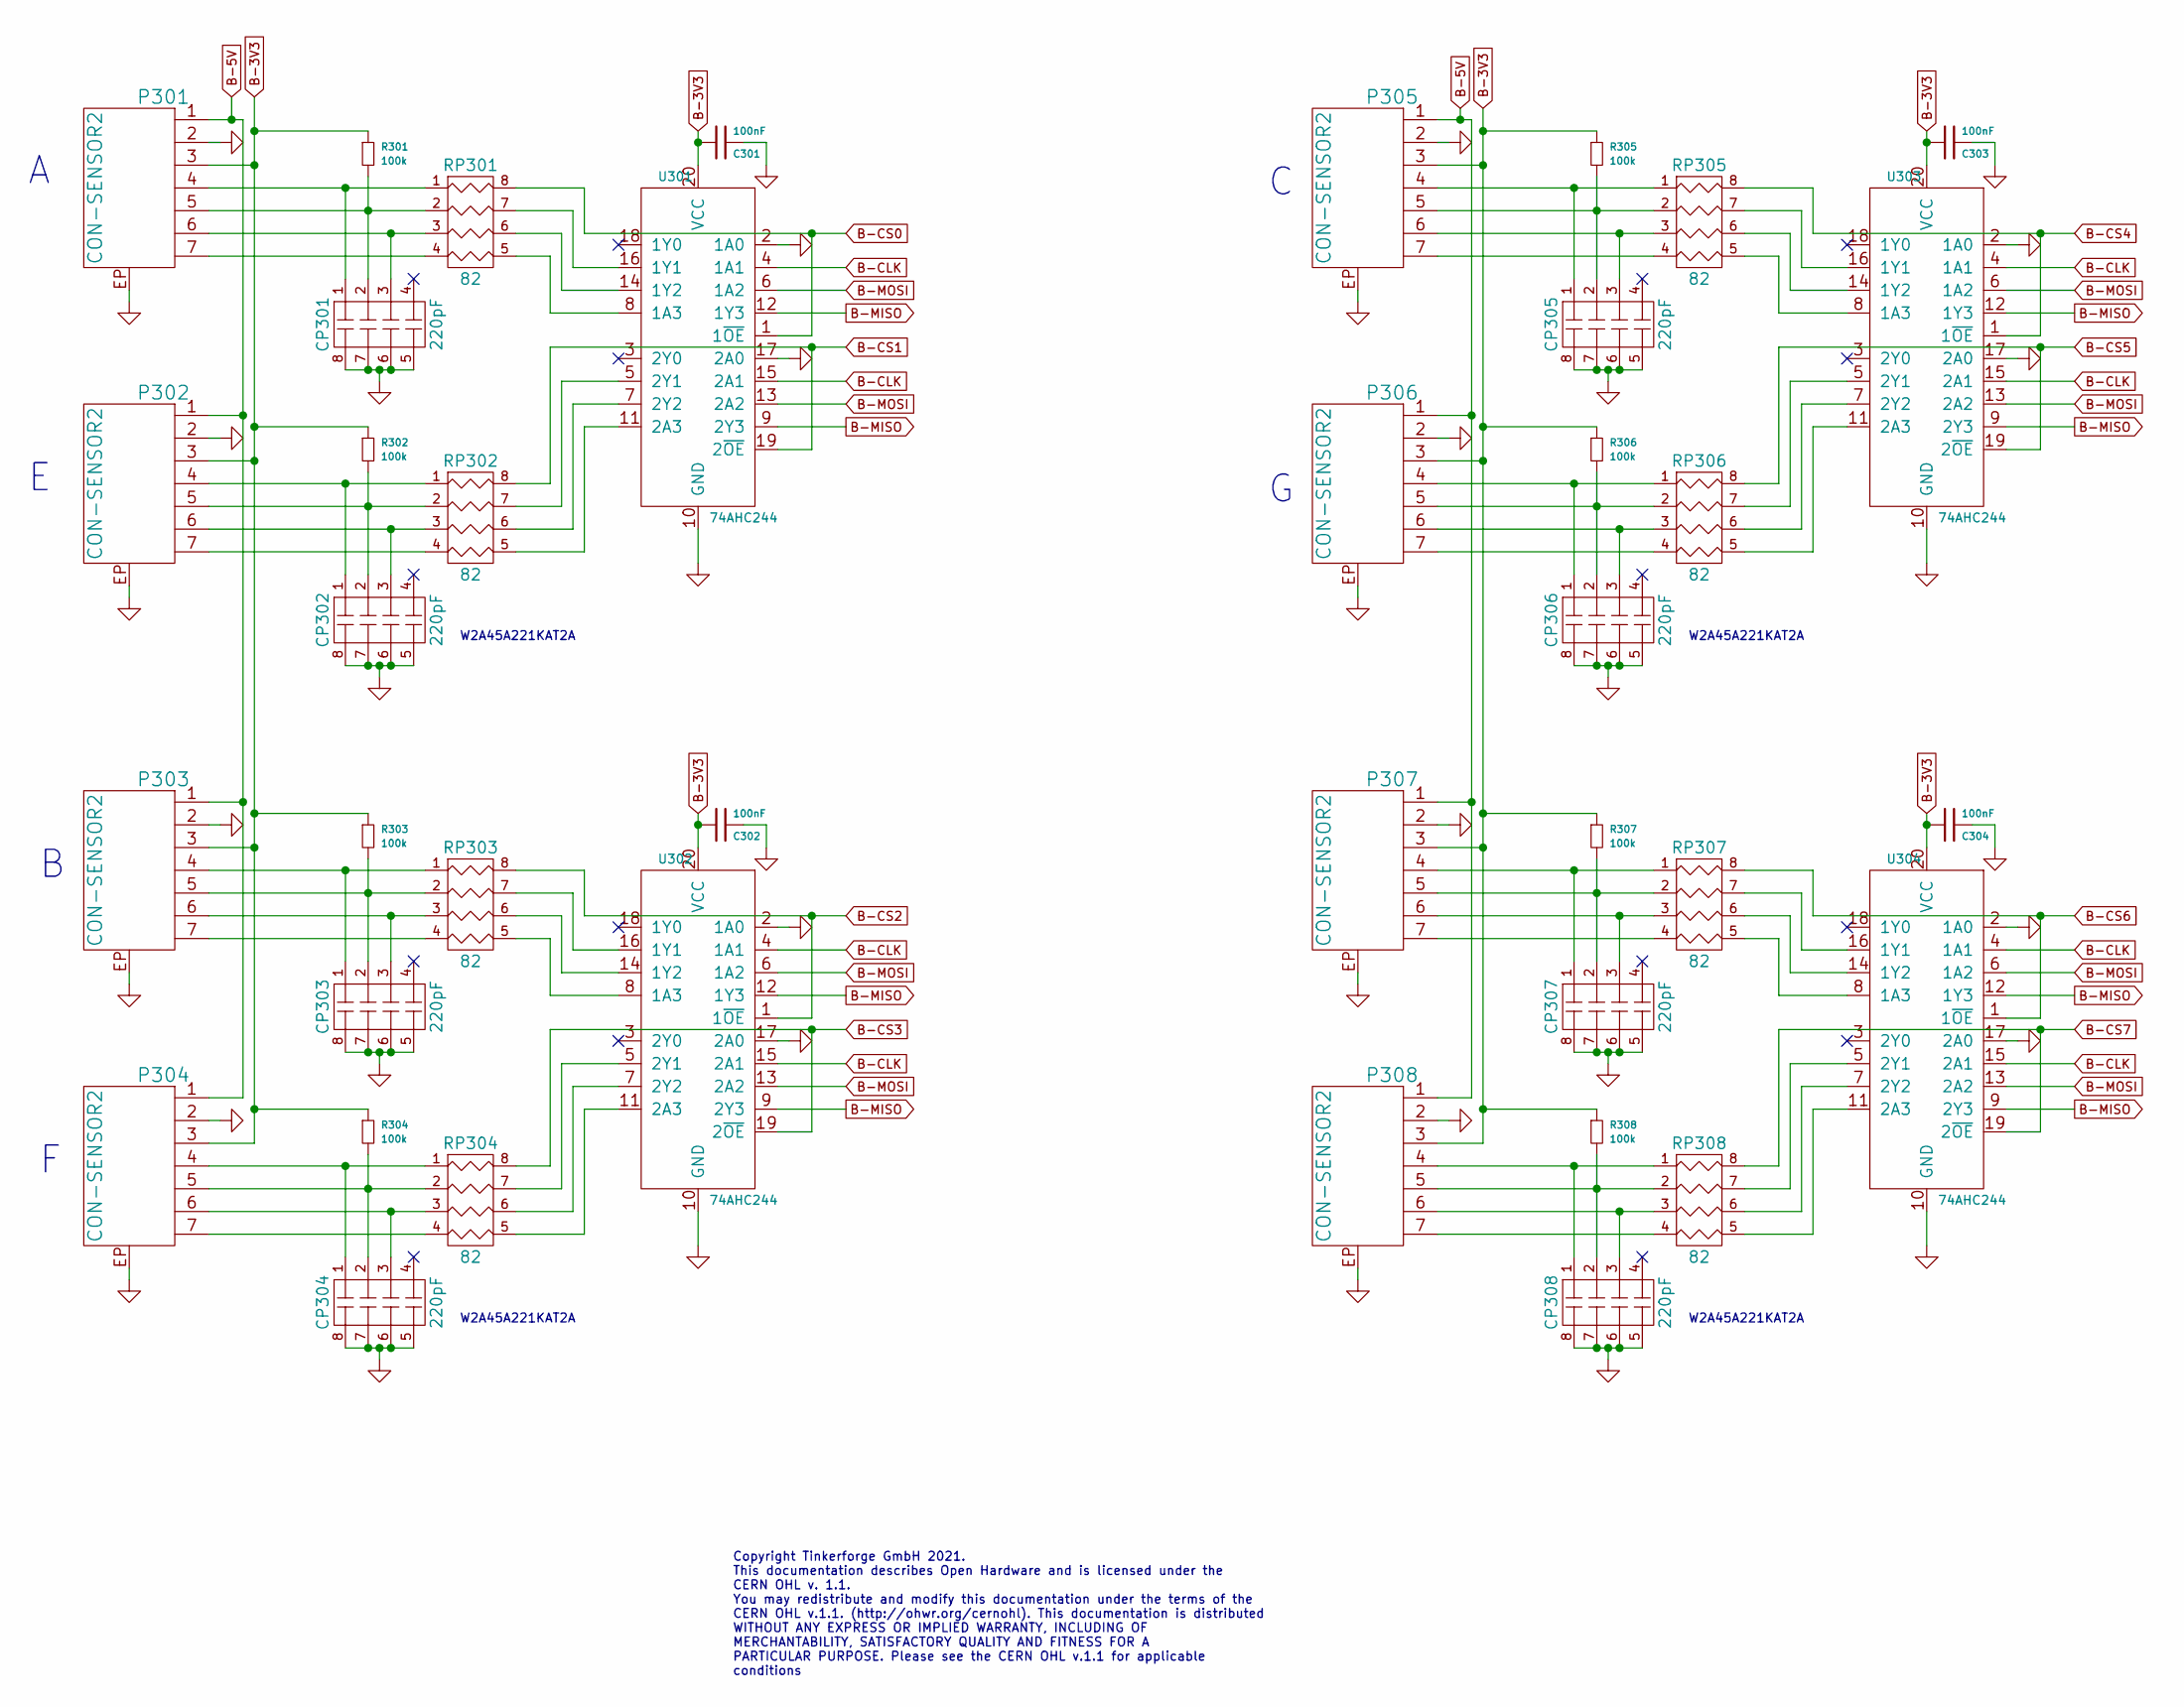
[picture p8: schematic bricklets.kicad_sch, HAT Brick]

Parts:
C301, C302, C303, C304: 100nF; C0603F
CP301, CP302, CP303, CP304, CP305, CP306, CP307, CP308: 220pF; 4X0402
P301, P302, P303, P304, P305, P306, P307, P308: CON-SENSOR2; CON-SENSOR2_180
R301, R302, R303, R304, R305, R306, R307, R308: 100k; R0402F
RP301, RP302, RP303, RP304, RP305, RP306, RP307, RP308: 82; 4X0402
U301, U302, U303, U304: 74AHC244; TSSOP20

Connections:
B-3V3: C301.2, C302.2, C303.2, C304.2, P301.3, P302.3, P303.3, P304.3, P305.3, P306.3, P307.3, P308.3, R301.1, R302.1, R303.1, R304.1, R305.1, R306.1, R307.1, R308.1, U301.20 (VCC), U302.20 (VCC), U303.20 (VCC), U304.20 (VCC); also elsewhere on the board
B-5V: P301.1, P302.1, P303.1, P304.1, P305.1, P306.1, P307.1, P308.1; also elsewhere on the board
B-CLK: U301.4 (1A1), U301.15 (2A1), U302.4 (1A1), U302.15 (2A1), U303.4 (1A1), U303.15 (2A1), U304.4 (1A1), U304.15 (2A1); also elsewhere on the board
B-CS0: RP301.8 (R1), U301.1 (1~OE); also elsewhere on the board
B-CS1: RP302.8 (R1), U301.19 (2~OE); also elsewhere on the board
B-CS2: RP303.8 (R1), U302.1 (1~OE); also elsewhere on the board
B-CS3: RP304.8 (R1), U302.19 (2~OE); also elsewhere on the board
B-CS4: RP305.8 (R1), U303.1 (1~OE); also elsewhere on the board
B-CS5: RP306.8 (R1), U303.19 (2~OE); also elsewhere on the board
B-CS6: RP307.8 (R1), U304.1 (1~OE); also elsewhere on the board
B-CS7: RP308.8 (R1), U304.19 (2~OE); also elsewhere on the board
B-MISO: U301.9 (2Y3), U301.12 (1Y3), U302.9 (2Y3), U302.12 (1Y3), U303.9 (2Y3), U303.12 (1Y3), U304.9 (2Y3), U304.12 (1Y3); also elsewhere on the board
B-MOSI: U301.6 (1A2), U301.13 (2A2), U302.6 (1A2), U302.13 (2A2), U303.6 (1A2), U303.13 (2A2), U304.6 (1A2), U304.13 (2A2); also elsewhere on the board
GND: C301.1, C302.1, C303.1, C304.1, CP301.5 (R4), CP301.6 (R3), CP301.7 (R2), CP301.8 (R1), CP302.5 (R4), CP302.6 (R3), CP302.7 (R2), CP302.8 (R1), CP303.5 (R4), CP303.6 (R3), CP303.7 (R2), CP303.8 (R1), CP304.5 (R4), CP304.6 (R3), CP304.7 (R2), CP304.8 (R1), CP305.5 (R4), CP305.6 (R3), CP305.7 (R2), CP305.8 (R1), CP306.5 (R4), CP306.6 (R3), CP306.7 (R2), CP306.8 (R1), CP307.5 (R4), CP307.6 (R3), CP307.7 (R2), CP307.8 (R1), CP308.5 (R4), CP308.6 (R3), CP308.7 (R2), CP308.8 (R1), P301.2, P301.EP, P302.2, P302.EP, P303.2, P303.EP, P304.2, P304.EP, P305.2, P305.EP, P306.2, P306.EP, P307.2, P307.EP, P308.2, P308.EP, U301.2 (1A0), U301.10 (GND), U301.17 (2A0), U302.2 (1A0), U302.10 (GND), U302.17 (2A0), U303.2 (1A0), U303.10 (GND), U303.17 (2A0), U304.2 (1A0), U304.10 (GND), U304.17 (2A0); also elsewhere on the board
unnamed: CP301.1, P301.4, RP301.1
unnamed: CP301.2, P301.5, R301.2, RP301.2
unnamed: CP301.3, P301.6, RP301.3
unnamed: CP302.1, P302.4, RP302.1
unnamed: CP302.2, P302.5, R302.2, RP302.2
unnamed: CP302.3, P302.6, RP302.3
unnamed: CP303.1, P303.4, RP303.1
unnamed: CP303.2, P303.5, R303.2, RP303.2
unnamed: CP303.3, P303.6, RP303.3
unnamed: CP304.1, P304.4, RP304.1
unnamed: CP304.2, P304.5, R304.2, RP304.2
unnamed: CP304.3, P304.6, RP304.3
unnamed: CP305.1, P305.4, RP305.1
unnamed: CP305.2, P305.5, R305.2, RP305.2
unnamed: CP305.3, P305.6, RP305.3
unnamed: CP306.1, P306.4, RP306.1
unnamed: CP306.2, P306.5, R306.2, RP306.2
unnamed: CP306.3, P306.6, RP306.3
unnamed: CP307.1, P307.4, RP307.1
unnamed: CP307.2, P307.5, R307.2, RP307.2
unnamed: CP307.3, P307.6, RP307.3
unnamed: CP308.1, P308.4, RP308.1
unnamed: CP308.2, P308.5, R308.2, RP308.2
unnamed: CP308.3, P308.6, RP308.3
unnamed: P301.7, RP301.4
unnamed: P302.7, RP302.4
unnamed: P303.7, RP303.4
unnamed: P304.7, RP304.4
unnamed: P305.7, RP305.4
unnamed: P306.7, RP306.4
unnamed: P307.7, RP307.4
unnamed: P308.7, RP308.4
unnamed: RP301.5 (R4), U301.8 (1A3)
unnamed: RP301.6 (R3), U301.14 (1Y2)
unnamed: RP301.7 (R2), U301.16 (1Y1)
unnamed: RP302.5 (R4), U301.11 (2A3)
unnamed: RP302.6 (R3), U301.7 (2Y2)
unnamed: RP302.7 (R2), U301.5 (2Y1)
unnamed: RP303.5 (R4), U302.8 (1A3)
unnamed: RP303.6 (R3), U302.14 (1Y2)
unnamed: RP303.7 (R2), U302.16 (1Y1)
unnamed: RP304.5 (R4), U302.11 (2A3)
unnamed: RP304.6 (R3), U302.7 (2Y2)
unnamed: RP304.7 (R2), U302.5 (2Y1)
unnamed: RP305.5 (R4), U303.8 (1A3)
unnamed: RP305.6 (R3), U303.14 (1Y2)
unnamed: RP305.7 (R2), U303.16 (1Y1)
unnamed: RP306.5 (R4), U303.11 (2A3)
unnamed: RP306.6 (R3), U303.7 (2Y2)
unnamed: RP306.7 (R2), U303.5 (2Y1)
unnamed: RP307.5 (R4), U304.8 (1A3)
unnamed: RP307.6 (R3), U304.14 (1Y2)
unnamed: RP307.7 (R2), U304.16 (1Y1)
unnamed: RP308.5 (R4), U304.11 (2A3)
unnamed: RP308.6 (R3), U304.7 (2Y2)
unnamed: RP308.7 (R2), U304.5 (2Y1)

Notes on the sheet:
W2A45A221KAT2A
Copyright Tinkerforge GmbH 2021. This documentation describes Open Hardware and is licensed under the CERN OHL v. 1.1. You may redistribute and modify this documentation under the terms of the CERN OHL v.1.1. (http://ohwr.org/cernohl). This documentation is distributed WITHOUT ANY EXPRESS OR IMPLIE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

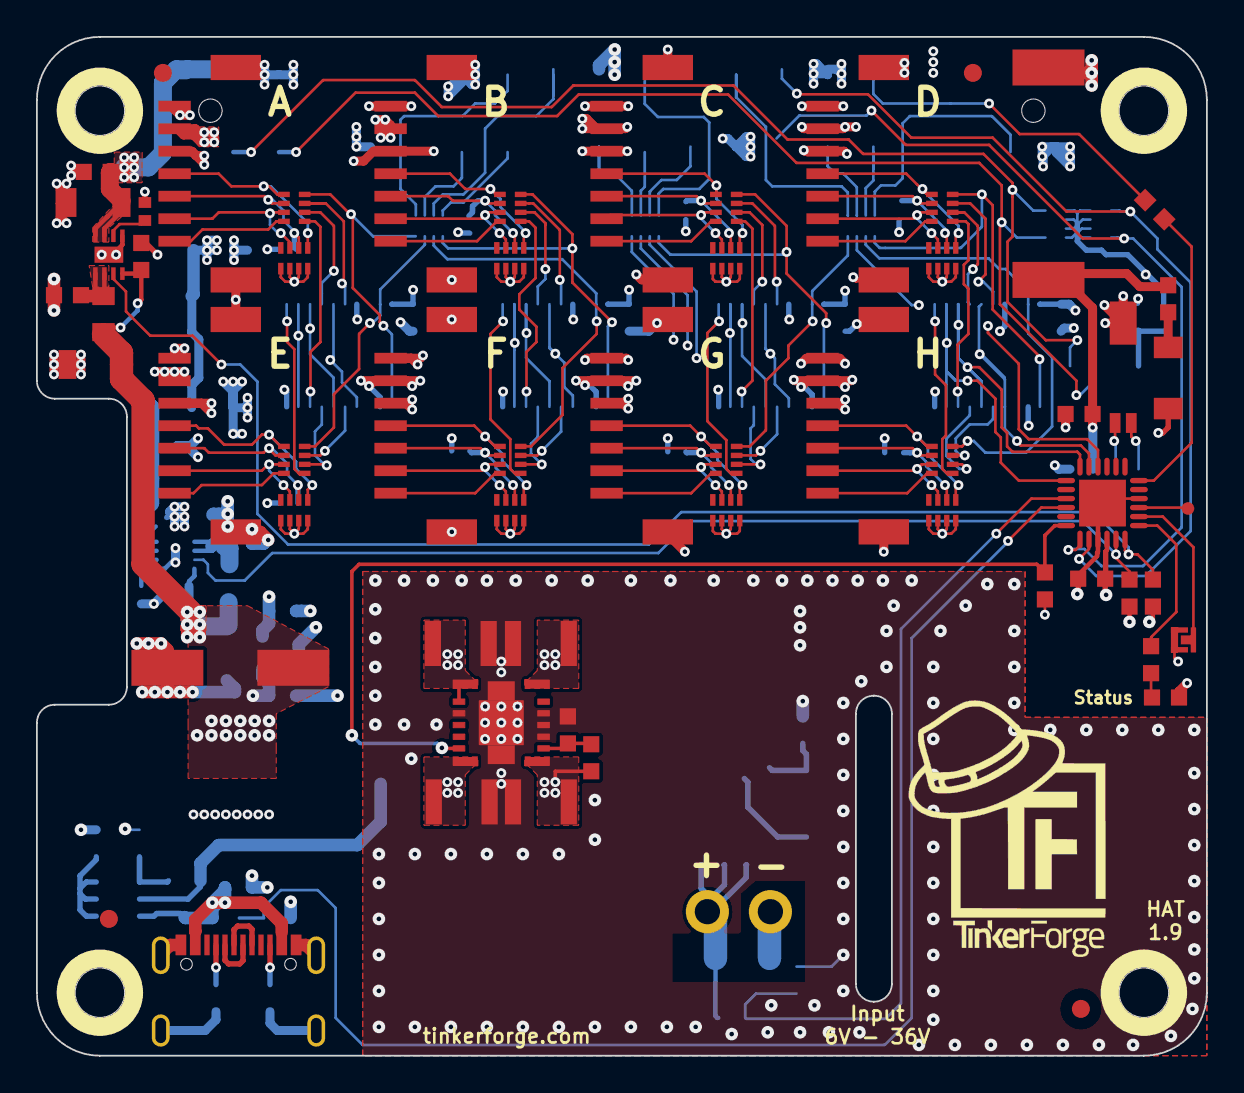
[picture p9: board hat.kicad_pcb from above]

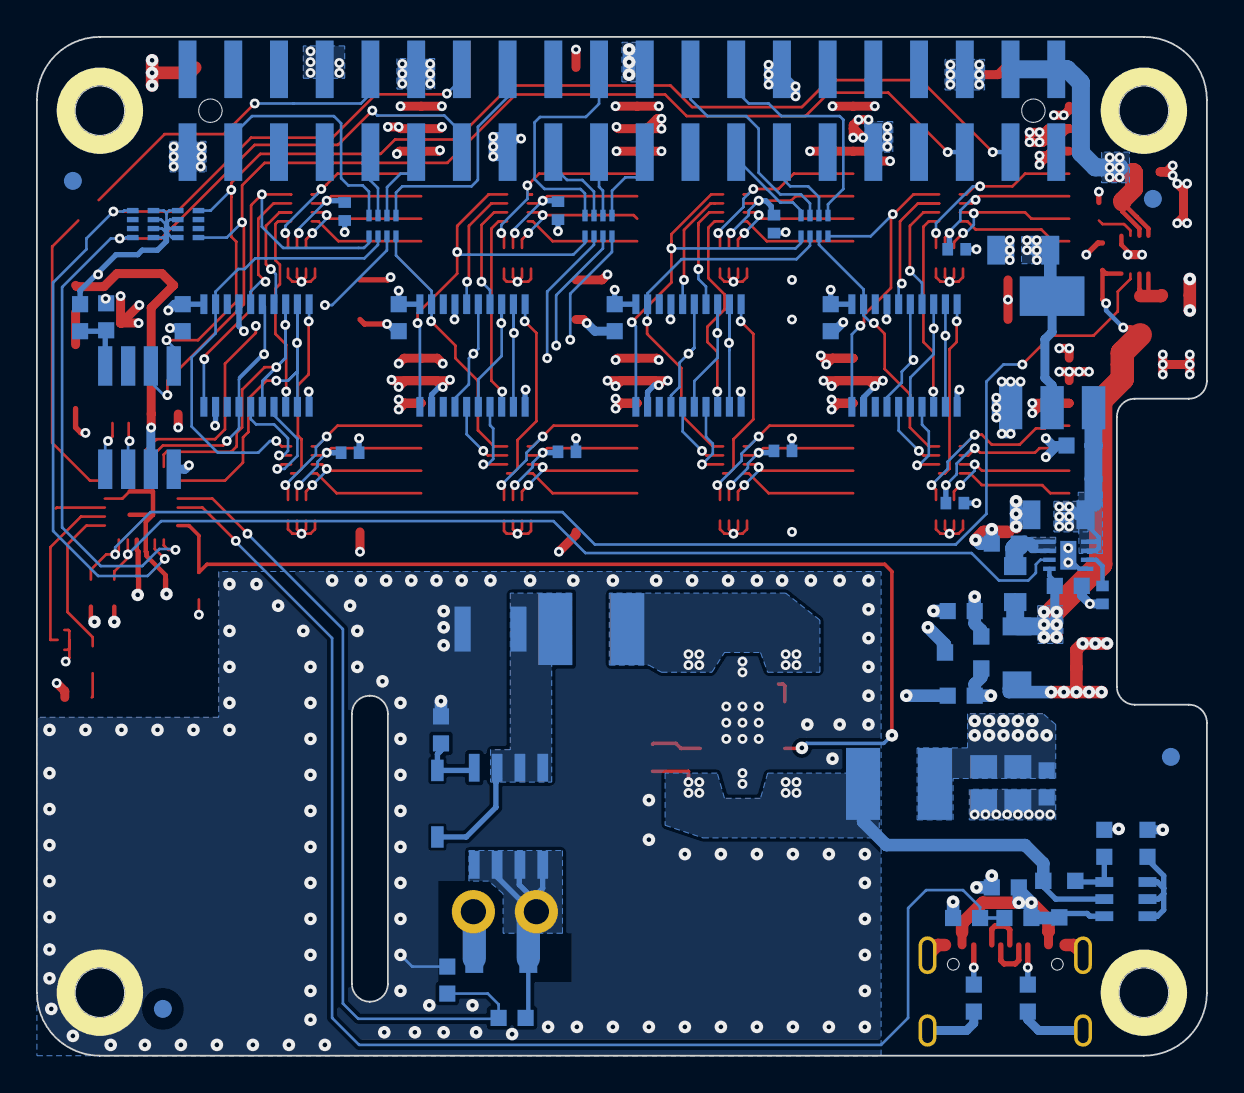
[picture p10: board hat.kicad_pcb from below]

Board: 4 copper layers, 65.0 x 56.6 mm, 124 parts (63 on the bottom side), 121 nets.

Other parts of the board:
Fiducial_Mark: VAL**; Fiducial_Mark
Fiducial_Mark#2, Fiducial_Mark#3, Fiducial_Mark#4, Fiducial_Mark#5, Fiducial_Mark#6, Fiducial_Mark#7, Fiducial_Mark#8: VAL**; Fiducial_Mark
R103: 1k; R0603F

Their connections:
unnamed 62: R103.2; also elsewhere on the board
RASP-GP: R103.1; also elsewhere on the board

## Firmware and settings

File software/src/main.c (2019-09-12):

/* hat-brick
 * Copyright (C) 2018-2019 Olaf Lüke <olaf@tinkerforge.com>
 *
 * main.c: Initialization for HAT Brick
 *
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
 * You should have received a copy of the GNU Lesser General Public
 * License along with this library; if not, write to the
 * Free Software Foundation, Inc., 59 Temple Place - Suite 330,
 * Boston, MA 02111-1307, USA.
 */

#include <stdio.h>
#include <stdbool.h>

#include "configs/config.h"

#include "bricklib2/bootloader/bootloader.h"
#include "bricklib2/hal/system_timer/system_timer.h"
#include "bricklib2/logging/logging.h"
#include "communication.h"

#include "rpi.h"
#include "eeprom.h"
#include "voltage.h"


int main(void) {
	logging_init();
	logd("Start HAT Brick\n\r");

	rpi_init();
	eeprom_init();
	voltage_init();
	communication_init();

	while(true) {
		bootloader_tick();
		rpi_tick();
		voltage_tick();
		communication_tick();
	}
}

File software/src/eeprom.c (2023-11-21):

/* hat-brick
 * Copyright (C) 2018, 2021 Olaf Lüke <olaf@tinkerforge.com>
 *
 * eeprom.c: EEPROM Emulation
 *
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
 * You should have received a copy of the GNU Lesser General Public
 * License along with this library; if not, write to the
 * Free Software Foundation, Inc., 59 Temple Place - Suite 330,
 * Boston, MA 02111-1307, USA.
 */

#include "eeprom.h"

#include "bricklib2/logging/logging.h"
#include "configs/config_eeprom.h"
#include "communication.h"

#include "eeprom_data.h"

#include "xmc_scu.h"

typedef enum XMC_I2C_CH_TDF {
	XMC_I2C_CH_TDF_MASTER_SEND         = 0,
	XMC_I2C_CH_TDF_SLAVE_SEND          = 1 << 8,
	XMC_I2C_CH_TDF_MASTER_RECEIVE_ACK  = 2 << 8,
	XMC_I2C_CH_TDF_MASTER_RECEIVE_NACK = 3 << 8,
	XMC_I2C_CH_TDF_MASTER_START        = 4 << 8,
	XMC_I2C_CH_TDF_MASTER_RESTART      = 5 << 8,
	XMC_I2C_CH_TDF_MASTER_STOP         = 6 << 8
} XMC_I2C_CH_TDF_t;

#define EEPROM_REGISTER_MASK 8191

#define eeprom_tx_handler       IRQ_Hdlr_12
#define eeprom_protocol_handler IRQ_Hdlr_11

// We use DS1307 and change it to PCF8523 if necessary by
// just changes the necessary bytes.
// We don't have enough space to save both EEPROM entries.
#if 0
#define EEPROM_DATA_PCF8523_LENGTH sizeof(eeprom_data_pcf8523)
extern const uint8_t eeprom_data_pcf8523[];
#define EEPROM_DATA_DS1307_LENGTH sizeof(eeprom_data_ds1307)
extern const uint8_t eeprom_data_ds1307[];
#endif

static volatile uint32_t eeprom_register = 0;

static uint8_t eeprom_register_high_byte = 0;
static bool eeprom_register_high_byte_received = false;

EEPROM eeprom;

void eeprom_settings_write(void) {
	uint32_t page[EEPROM_PAGE_SIZE/sizeof(uint32_t)];

	page[CALIBRATION_MAGIC_POS] = CALIBRATION_MAGIC;
	page[CALIBRATION_RTC_POS]   = eeprom.rtc_driver;

	if(!bootloader_write_eeprom_page(CALIBRATION_PAGE, page)) {
		// TODO: Error handling?
		return;
	}
}

void eeprom_settings_read(void) {
	uint32_t page[EEPROM_PAGE_SIZE/sizeof(uint32_t)];

	bootloader_read_eeprom_page(CALIBRATION_PAGE, page);

	// The magic number is not where it is supposed to be.
	// This is either our first startup or something went wrong.
	// We initialize the calibration data with sane default values.
	if(page[CALIBRATION_MAGIC_POS] != CALIBRATION_MAGIC) {
		eeprom.rtc_driver = HAT_RTC_DRIVER_PCF8523; // PCF8523 is default

		return;
	}

	eeprom.rtc_driver = page[CALIBRATION_RTC_POS];
}

void eeprom_init(void) {
	memset(&eeprom, 0, sizeof(EEPROM));

	eeprom_settings_read();

	if(eeprom.rtc_driver == HAT_RTC_DRIVER_PCF8523) {
		EEPROM_PATCH_TO_PCF8523();
	}

	XMC_I2C_CH_Stop(EEPROM_I2C);
	const XMC_GPIO_CONFIG_t input_config =  {
		.mode         = XMC_GPIO_MODE_INPUT_TRISTATE,
		.output_level = XMC_GPIO_OUTPUT_LEVEL_HIGH,
	};

	XMC_GPIO_Init(EEPROM_SCL_PIN, &input_config);
	XMC_GPIO_Init(EEPROM_SDA_PIN, &input_config);

	const XMC_I2C_CH_CONFIG_t i2c_slave_config = {
		.baudrate = EEPROM_I2C_BAUDRATE,
		.address  = EEPROM_I2C_ADDRESS
	};

	const XMC_GPIO_CONFIG_t scl_pin_config = {
		.mode         = EEPROM_SCL_PIN_MODE,
		.output_level = XMC_GPIO_OUTPUT_LEVEL_HIGH,
	};

	const XMC_GPIO_CONFIG_t sda_pin_config = {
		.mode         = EEPROM_SDA_PIN_MODE,
		.output_level = XMC_GPIO_OUTPUT_LEVEL_HIGH,
    };

	XMC_I2C_CH_Init(EEPROM_I2C, &i2c_slave_config);

	XMC_I2C_CH_SetInputSource(EEPROM_I2C, EEPROM_SDA_INPUT, EEPROM_SDA_SOURCE);
	XMC_I2C_CH_SetInputSource(EEPROM_I2C, EEPROM_SCL_INPUT, EEPROM_SCL_SOURCE);

	XMC_USIC_CH_TXFIFO_Configure(EEPROM_I2C, EEPROM_TX_FIFO_POINTER, EEPROM_TX_FIFO_SIZE, 8);
	XMC_USIC_CH_TXFIFO_SetInterruptNodePointer(EEPROM_I2C, XMC_USIC_CH_TXFIFO_INTERRUPT_NODE_POINTER_STANDARD, 3);

	XMC_USIC_CH_RXFIFO_Configure(EEPROM_I2C, EEPROM_RX_FIFO_POINTER, EEPROM_RX_FIFO_SIZE, 8);

	XMC_USIC_CH_SetInterruptNodePointer(EEPROM_I2C, XMC_USIC_CH_INTERRUPT_NODE_POINTER_PROTOCOL, 2);
	XMC_I2C_CH_Start(EEPROM_I2C);

	XMC_GPIO_Init(EEPROM_SCL_PIN, &scl_pin_config);
	XMC_GPIO_Init(EEPROM_SDA_PIN, &sda_pin_config);

	NVIC_SetPriority(12, 1); // tx
	NVIC_EnableIRQ(12);
	NVIC_SetPriority(11, 0); // protocol
	NVIC_EnableIRQ(11);
	XMC_I2C_CH_EnableEvent(EEPROM_I2C, XMC_I2C_CH_EVENT_SLAVE_READ_REQUEST | XMC_I2C_CH_EVENT_ERROR);
}


void __attribute__((optimize("-O3"))) __attribute__ ((section (".ram_code"))) eeprom_tx_handler(void) {
	// Fill fifo (if the read transfer stops we flush the fifo again)
	while(!XMC_USIC_CH_TXFIFO_IsFull(EEPROM_I2C)) {
		EEPROM_I2C->IN[0] = XMC_I2C_CH_TDF_SLAVE_SEND | eeprom_data[eeprom_register];
		eeprom_register = (eeprom_register + 1) & EEPROM_REGISTER_MASK;
	}
}

void __attribute__((optimize("-O3"))) __attribute__ ((section (".ram_code"))) eeprom_protocol_handler(void) {
    uint32_t status = XMC_I2C_CH_GetStatusFlag(EEPROM_I2C);

	// In case of stop condition or error we reset the tx fifo and i2c state machine
	if(status & (XMC_I2C_CH_STATUS_FLAG_ERROR | XMC_I2C_CH_STATUS_FLAG_STOP_CONDITION_RECEIVED)) {
		XMC_USIC_CH_TXFIFO_DisableEvent(EEPROM_I2C, XMC_USIC_CH_TXFIFO_EVENT_CONF_STANDARD);
		XMC_USIC_CH_TXFIFO_ClearEvent(EEPROM_I2C, XMC_USIC_CH_TXFIFO_EVENT_CONF_STANDARD);
		XMC_USIC_CH_TXFIFO_Flush(EEPROM_I2C);
		XMC_USIC_CH_SetTransmitBufferStatus(EEPROM_I2C, 0b10); // Clear bits TDV and TE

		// In case of error we re-initialize the whole thing.
		if(status & XMC_I2C_CH_STATUS_FLAG_ERROR) {
			eeprom_init();
		}

		XMC_I2C_CH_ClearStatusFlag(XMC_I2C0_CH1, XMC_I2C_CH_STATUS_FLAG_ERROR | XMC_I2C_CH_STATUS_FLAG_STOP_CONDITION_RECEIVED);
	}

	if(status & XMC_I2C_CH_STATUS_FLAG_SLAVE_READ_REQUESTED) {
		while(!XMC_USIC_CH_RXFIFO_IsEmpty(EEPROM_I2C)) {
			// In case of a read request we set the register variable to the
			// desired register.
            if(!eeprom_register_high_byte_received) {
                eeprom_register_high_byte = XMC_I2C_CH_GetReceivedData(EEPROM_I2C);
                eeprom_register_high_byte_received = true;
            } else {
			    eeprom_register = ((eeprom_register_high_byte << 8) | XMC_I2C_CH_GetReceivedData(EEPROM_I2C)) & EEPROM_REGISTER_MASK;
                eeprom_register_high_byte_received = false;
                eeprom_register_high_byte = 0;

                // Fill buffer with data starting from address.
				XMC_USIC_CH_TXFIFO_Flush(EEPROM_I2C);
                eeprom_tx_handler();
                XMC_USIC_CH_TXFIFO_ClearEvent(EEPROM_I2C, XMC_USIC_CH_TXFIFO_EVENT_CONF_STANDARD);
                XMC_USIC_CH_TXFIFO_EnableEvent(EEPROM_I2C, XMC_USIC_CH_TXFIFO_EVENT_CONF_STANDARD);
            }

		}

		XMC_I2C_CH_ClearStatusFlag(EEPROM_I2C, XMC_I2C_CH_STATUS_FLAG_SLAVE_READ_REQUESTED);
	}

	// If we receive bytes after the register number we read the data
	// and throw it away (we don't have any writable registers).
	if(status & XMC_I2C_CH_STATUS_FLAG_RECEIVE_INDICATION) {
		while(!XMC_USIC_CH_RXFIFO_IsEmpty(EEPROM_I2C)) {
			uint32_t __attribute__((unused)) _ = XMC_I2C_CH_GetReceivedData(EEPROM_I2C);
		}

		XMC_I2C_CH_ClearStatusFlag(EEPROM_I2C, XMC_I2C_CH_STATUS_FLAG_RECEIVE_INDICATION);
	}
}

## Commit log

2018-06-27 partial schematics added
    [bricklets.sch, hat.sch, power_supply.sch]
2018-06-27 schematic improved
    [bricklets.sch, hat.sch, power_supply.sch]
2018-06-28 partial placement
    [bricklets.sch, hat.kicad_pcb, hat.sch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]
2018-07-06 partial routing
    [bricklets.sch, hat.kicad_pcb, hat.sch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]
2018-07-09 more placement/routing
    [bricklets.sch, hat.kicad_pcb, hat.sch]
2018-07-09 more routing
    [hat.kicad_pcb, hat.sch]
2018-07-10 more routing, fix 3d view
    [hat.kicad_pcb, hat.sch]
2018-07-11 change step down routing
    [bricklets.sch, hat.kicad_pcb, hat.sch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]
2018-07-11 datalines routed
    [hat.kicad_pcb, hat.sch]
2018-07-11 leds added, routing nearly complete
    [bricklets.sch, hat.kicad_pcb, hat.sch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]
2018-07-11 fix 3d view
    [hat.kicad_pcb]
2018-07-12 everything connected, routing finished, optimizations missing
    [hat.kicad_pcb, hat.sch]
2018-07-12 finished prototype
    [bricklets.sch, hat.kicad_pcb, hat.sch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]
2018-07-12 ordered version
    [hat.kicad_pcb]
2018-07-13 Add missing 3d models
    [hat.kicad_pcb]
2018-07-17 specify parts
    [hat.kicad_pcb, power_supply.sch]
2018-07-26 values specified
    [hat.kicad_pcb, power_supply.sch]
2018-07-26 resistor specification added (was unsaved before)
    [power_supply.sch]
2018-07-31 fix raspberry pi hat female header footprint
    not every signal fixed
    [bricklets.sch, hat.kicad_pcb, hat.sch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]
2018-07-31 Add auto-generated stub firmware
    [cmake_config_custom.txt]
2018-08-01 Use correct status LED
    [config_custom_bootloader.h, config_custom_bootstrapper.h]
2018-08-06 raspberry pi footprint increase, not every signal fixed
    [bricklets.sch, hat.kicad_pcb, hat.sch]
2018-08-06 swap cs2 and cs3, fix routing
    [hat.kicad_pcb, hat.sch, power_supply.sch]
2018-08-06 thermal improvement
    [hat.kicad_pcb]
2018-08-06 bugfixing
    * swap RASP-SD, RASP-SC
    * remove current setting of bq24075 -> fixed by resistor
    * remove sysoff -> fix on
    [bricklets.sch, hat.sch, power_supply.sch]
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2018-08-07 completely routed, optimzations missing.
    [bricklets.sch, hat.kicad_pcb, hat.sch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]
2018-08-07 fix text positions
    [hat.kicad_pcb]
2018-08-08 routing and thermal optimzations
    [hat.kicad_pcb]
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2018-08-08 fix battery connector
    [hat.kicad_pcb]
2018-08-09 add slide switch for sysoff
    [hat.kicad_pcb, power_supply.sch]
2018-08-09 remove 16mhz crystal, add capacitors for 32kHz Crystal
    [hat.kicad_pcb, hat.sch]
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2018-08-10 change additional bricklet clock pin to P0.6
    [hat.kicad_pcb, hat.sch]
2018-08-13 update slide switch footprint
    [hat.kicad_pcb]
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2018-08-22 specify crystal capacitors 10pF
    [hat.kicad_pcb, hat.sch]
2018-08-22 add bug hint
    [hat.kicad_pcb, hat.sch]
2018-08-22 Use RTC for DCO1 calibration, fix prescaler and preload values
    [config_custom_bootloader.h]
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2018-08-31 change power management to bq2195, add ideal usb diode
    [hat.kicad_pcb, hat.sch, power_supply.sch]
2018-09-03 change power management chip to bq241905
    [hat.kicad_pcb, hat.sch, power_supply.sch]
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2018-09-04 hat version 1.1 finished
    [hat.kicad_pcb, power_supply.sch]
2018-09-13 Use mutex for i2c, since we have bq and max on same i2c bus
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2018-09-13 Add test driver for BQ24195
    Currently only reads and prints out all of the available registers
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2018-09-24 add hints
    [hat.kicad_pcb, hat.sch, power_supply.sch]
2018-09-24 version 1.2
    * add boost converter to PMIC
    * remove unnecessary signals
    * move erase
    * move bricklet and raspberry control pins
    [hat.kicad_pcb, hat.sch, power_supply.sch]
2018-09-25 fix capacitor position
    [hat.kicad_pcb]
2018-10-05 respecify resistor
    [hat.kicad_pcb, power_supply.sch]
2018-10-08 Fix boot pad pin (use newest hardware version)
    [config_custom_bootloader.h]
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2018-10-08 Handle under-voltage correctly
    Turn boost as well as rpi and bricklets off, but only turn
    rpi/bricklet on again (after there is no under-voltage anymore)
    if they were on before.
    [rpi.c]
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2018-10-09 routing improvement
    [hat.kicad_pcb]
2018-10-10 move on/off switch, improve text positions, move resistornet
    [hat.kicad_pcb]
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2018-10-23 change boost enable pulldown to a pullup
    [hat.kicad_pcb, power_supply.sch]
2018-10-24 change battery connector position
    [hat.kicad_pcb, power_supply.sch]
2018-10-24 update descriptions
    [hat.kicad_pcb, hat.sch]
2018-10-25 Remove TTE/TTF parameter from API
    This feature of the max17260 does unfortunately not work good enough
    [communication.h]
2019-02-18 version 1.3
    * remove battery stuff (management, charger)
    * new step down power supply based on BD906XX
    [hat.kicad_pcb, hat.sch, power_supply.sch]
2019-02-19 add version 1.3
    * change power switches to tps22975
    [hat.kicad_pcb, hat.sch, power_supply.sch]
2019-02-20 add 3d models of inductor and step down
    [hat.kicad_pcb]
2019-02-21 add version 1.4
    * rtc connected to pi
    * xmc1400 -> xmc1xxx
    [hat.kicad_pcb, hat.sch]
2019-03-05 specify ferrites
    [hat.kicad_pcb, hat.sch]
2019-03-05 fix diode name
    [hat.kicad_pcb, hat.sch]
2019-03-14 Modify firmware for changes in newest hardware version (HAT 1.4)
    Remove support for MAX17260 and BQ24195. The UPS circuitry has
    been moved to an external board.
    [cmake_config_custom.txt]
2019-03-19 changed TF logo
    [hat.kicad_pcb]
2019-04-03 production data generated
    [hat.kicad_pcb]
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2019-04-29 add production data
    [hat-bom.xls, hat-bottom.xls, hat-top.xls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]
2019-04-29 remove data
    [hat-bom.xls, hat-bottom.xls, hat-top.xls]
2019-07-01 add schematic, fix descriptions
    [bricklets.sch, hat.kicad_pcb, hat.sch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]
2019-07-01 add 3d data
    [hat.FCStd]
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2020-03-24 fix values
    [bricklets.sch, hat.kicad_pcb, hat.sch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]
2020-03-25 add version 1.5
    * improve rtc circuitry
    * add bricklet clock pullup possibility
    * improve step down power supply
    * add USB C
    [bricklets.sch, hat.kicad_pcb, hat.sch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]
2020-05-15 version 1.5 release
    [bricklets.sch, hat.kicad_pcb, hat.sch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]
2020-06-02 add bottom fiducials
    [hat.kicad_pcb]
2020-06-02 fix text
    [hat.kicad_pcb, power_supply.sch]
2020-06-02 fix name
    [hat.kicad_pcb, power_supply.sch]
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2020-08-03 add 100k pullup resistors for SPI comm
    [bricklets.sch, hat.kicad_pcb]
2020-08-25 add version 1.6
    * fix USB-C cc1 and cc2 resistors
    [bricklets.sch, hat.kicad_pcb, hat.sch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]
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2020-09-28 fix rtc: change cap, change cap voltage to 3.3V
    [hat.kicad_pcb, hat.sch]
2020-10-16 uc: Fix divisor type.
    [example_print_voltages.c]
2020-12-07 test: Also test get-identity in addition to enumerate callback
    There is a specific soldering issue that results in enumerate working
    but other communication with the Bricklet failing.
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2021-10-04 add version 1.7
    add step down filters
    [bricklets.sch, hat.kicad_pcb, hat.sch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]
2021-10-25 Update KiCad link
    https://www.kicad.org/blog/2021/10/Avoid-links-to-former-kicad-domain/
2022-04-27 uc: Adapt to bindings changes
    [example_print_voltages.c]
2023-05-10 switched to kicad 6
    [bricklets.kicad_sch, bricklets.sch, hat.kicad_pcb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]
2023-06-01 Proto V1.8
    [hat.kicad_pcb, hat.kicad_sch, power_supply.kicad_sch]
2023-06-02 ready for prototype
    [hat.kicad_pcb]
2023-06-05 changed D101
    [hat.kicad_pcb, hat.kicad_sch]
2023-06-29 Hardware V1.9 changed zone infill on the + side of OQ2
    [bricklets.kicad_sch, hat.kicad_pcb, hat.kicad_sch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]
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2023-07-11 hardware: changed input silkscreen to 6V-36V
    [hat.kicad_pcb]
2023-11-21 Add support for Raspberry Pi 5. Auto-generate EEPROM patch.
    RPi 5 requires 'compatible = "brcm,bcm2712";' in the dts files. Also
    on a Pi 5 using the CS pin as GPIO is not allowed anymore. To fix this,
    disable the spi0's CS pin.
    This commit also adds a script that auto-generates the EEPROM patch to
    switch between the DS1307 and PCF8523 variants of the device tree
    overlay.
    [eeprom.c]
2023-12-05 move to kicad 7
    [bricklets.kicad_sch, hat.kicad_pcb, hat.kicad_sch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]
2023-12-05 add fiducials
    [hat.kicad_pcb]
2024-02-22 update files for hat 1.8
    [hat.FCStd]

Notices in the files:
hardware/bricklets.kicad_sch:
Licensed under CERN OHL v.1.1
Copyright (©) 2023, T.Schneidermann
